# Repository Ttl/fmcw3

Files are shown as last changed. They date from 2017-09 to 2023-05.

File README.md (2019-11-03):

# 6 GHz two RX channel FMCW radar design files.

For more information see: https://hforsten.com/third-version-of-homemade-6-ghz-fmcw-radar.html

## SAR image formation steps:

Compile Tensorflow custom operations in `pc/sar/sar_op`. See `BUILDING` file in
that directory for the instructions.

`pc/sar/process_sweeps.py` is used to slice the correct time from the measurement file.

`./process_sweeps.py <log file> <start time> <end time> [decimation factor]`

It writes `sweeps.p` file with the data in the format the image formation scripts know how to read.
To form the SAR image run `./backprojection_tf.py sweeps.p` or `./omegak_tf.py sweeps.p`.
Some variables related to the image formation can be found on the top of the image formation scripts.

Example data can be downloaded from: https://hforsten.com/fmcw3/parking_lot_sar.log

Use start and end times of 20 and 136 for it. Decimation factor should be 1 or
2 for backprojection and 2 for omega-k.

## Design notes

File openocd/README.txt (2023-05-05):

Programs the radar board FPGA and flash memory.

Openocd version 0.11.0 recommended.

To program the FPGA without flash:
$ openocd -f program_fpga.cfg 

To program flash:
$ openocd -f program_flash.cfg

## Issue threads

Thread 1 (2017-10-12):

Have you consider to sell it?

sken79, 2017-10-12:
Your project is impressive, but difficult to realize by newbie: have you consider to sell it?

Ttl, 2017-10-13:
I have considered it, but I'm not going to sell them. Manufacturing them myself would require too much time for it to be worth it and I don't think that there is enough demand for larger scale production. There are also potential legal issues with selling radio devices that can transmit on frequency bands that require license.

Closed 2017-10-13.

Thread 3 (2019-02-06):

Bill of Materials Challenges

zack-emmert, 2019-02-06:
Once again attempting to track down all of the components involved, a large number of entries lack the information necessary to locate them. The majority of entries lack a Manufacturer Part Number, making it very difficult to track down the components. Examples include the 15dB Coupler, and "C_0402b 10n." I have precisely no clue what the second component actually is, and there is significant ambiguity locating the first one. Clarification regarding the MPNs of many of the components would be very helpful.

Ttl, 2019-02-06:
"15 dB Coupler" is the coupler on PA output made of PCB traces, there is nothing to populate.

"C_0402b" is 0402 capacitor footprint. 10n is the value.

I know it could be clearer, but I don't have the time or motivation to fill the manufacturer part numbers. Both of these should have been clear if you would have looked them up in the schematic.

Closed 2019-02-06.

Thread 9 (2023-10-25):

Design Rule Check (DRC) problems of fmcw3

bigbenbell, 2023-10-25:
Dear Henrik,

You really contributed a beautiful fmcw radar design. We are trying to build our own radar system using the design of fmcw3. When outputting Gerber files, there were a large number of errors during running DRC. For example:
1 Error: Annular width (board setup constraints...n annular width 0.1000 mm; actual 0.0000 mm)
2 Error: Clearance violation (netclass 'Default' clearance 0.1300 mm; actual 0.0000 mm)
3 Error: Hole clearance violation...
4 Error: Courtyards overlap...
5 Error: Drill out of range...

**I'm not sure if this will affect the homemade radar.**

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

Closed 2023-10-25.

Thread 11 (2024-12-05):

fmcw board problem

mjk1376, 2024-12-05:
hello, i have order your board from osh and buy it's component and solder them but i have problem. vivado can not determine fpga. i change eeprom ic and program it with my own hex file and when i attach cable the computer show device attachment in device manager but vivado in auto-connect mode it did not know the board. all the voltages are correct. board after attaching to 12 v consume 0.19 A and after i attach type-b cable it show 0.21 A. can you give me hint about the problem.
thanks

Ttl, 2024-12-05:
Vivado is not supported. You need to use openocd. See `openocd` folder.

Closed 2024-12-05.

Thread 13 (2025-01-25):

how to test board

mjk1376, 2025-01-25:
Hello
I have ordered the board and its components. After addressing a few challenges, I am pleased to report that the board's voltage levels are now correct, and the FPGA has been successfully programmed with your provided configuration. The output current is 250mA, as indicated in the schematic. However, there is no signal present at the TX output. Could you kindly advise on the recommended steps for testing the RF component of the board?

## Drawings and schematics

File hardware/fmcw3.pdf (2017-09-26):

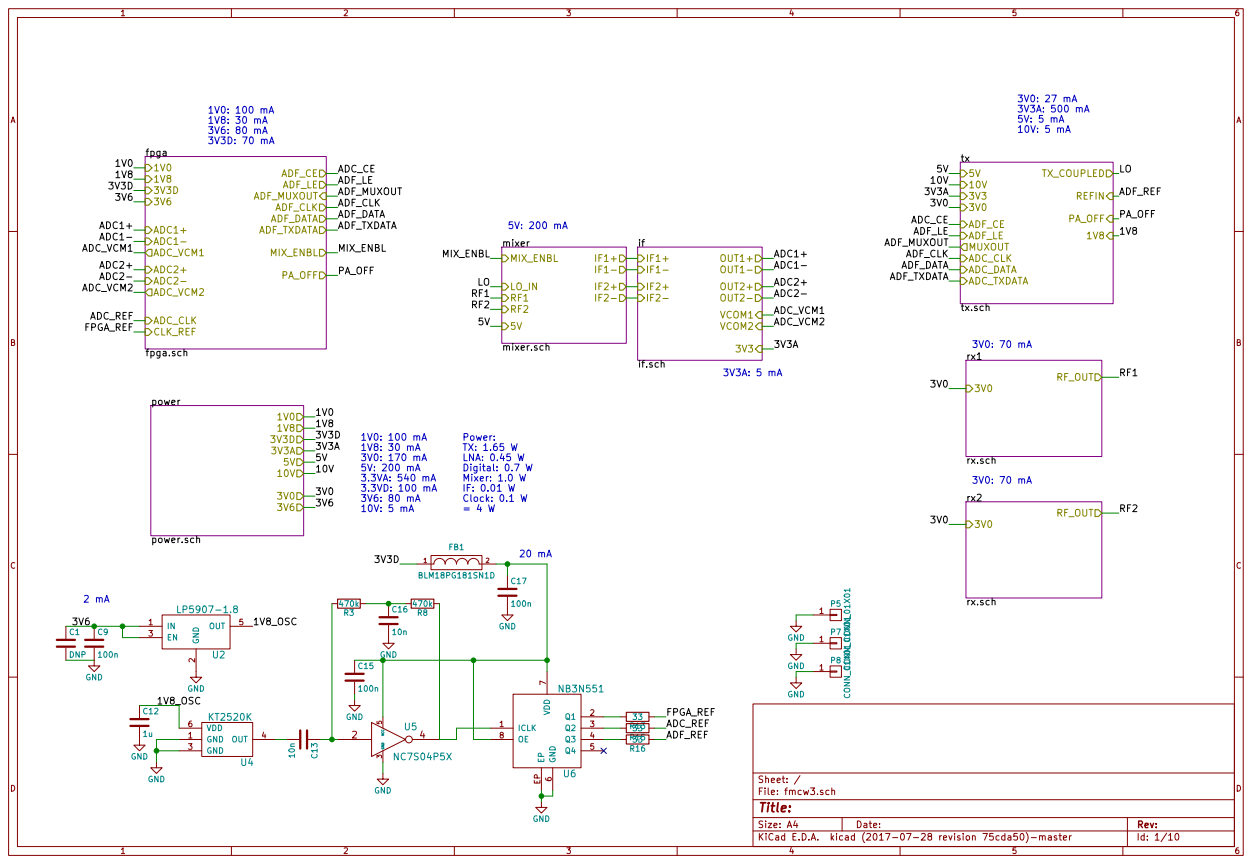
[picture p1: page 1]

Id: 1/10 Title: File: fmcw3.sch Sheet: /

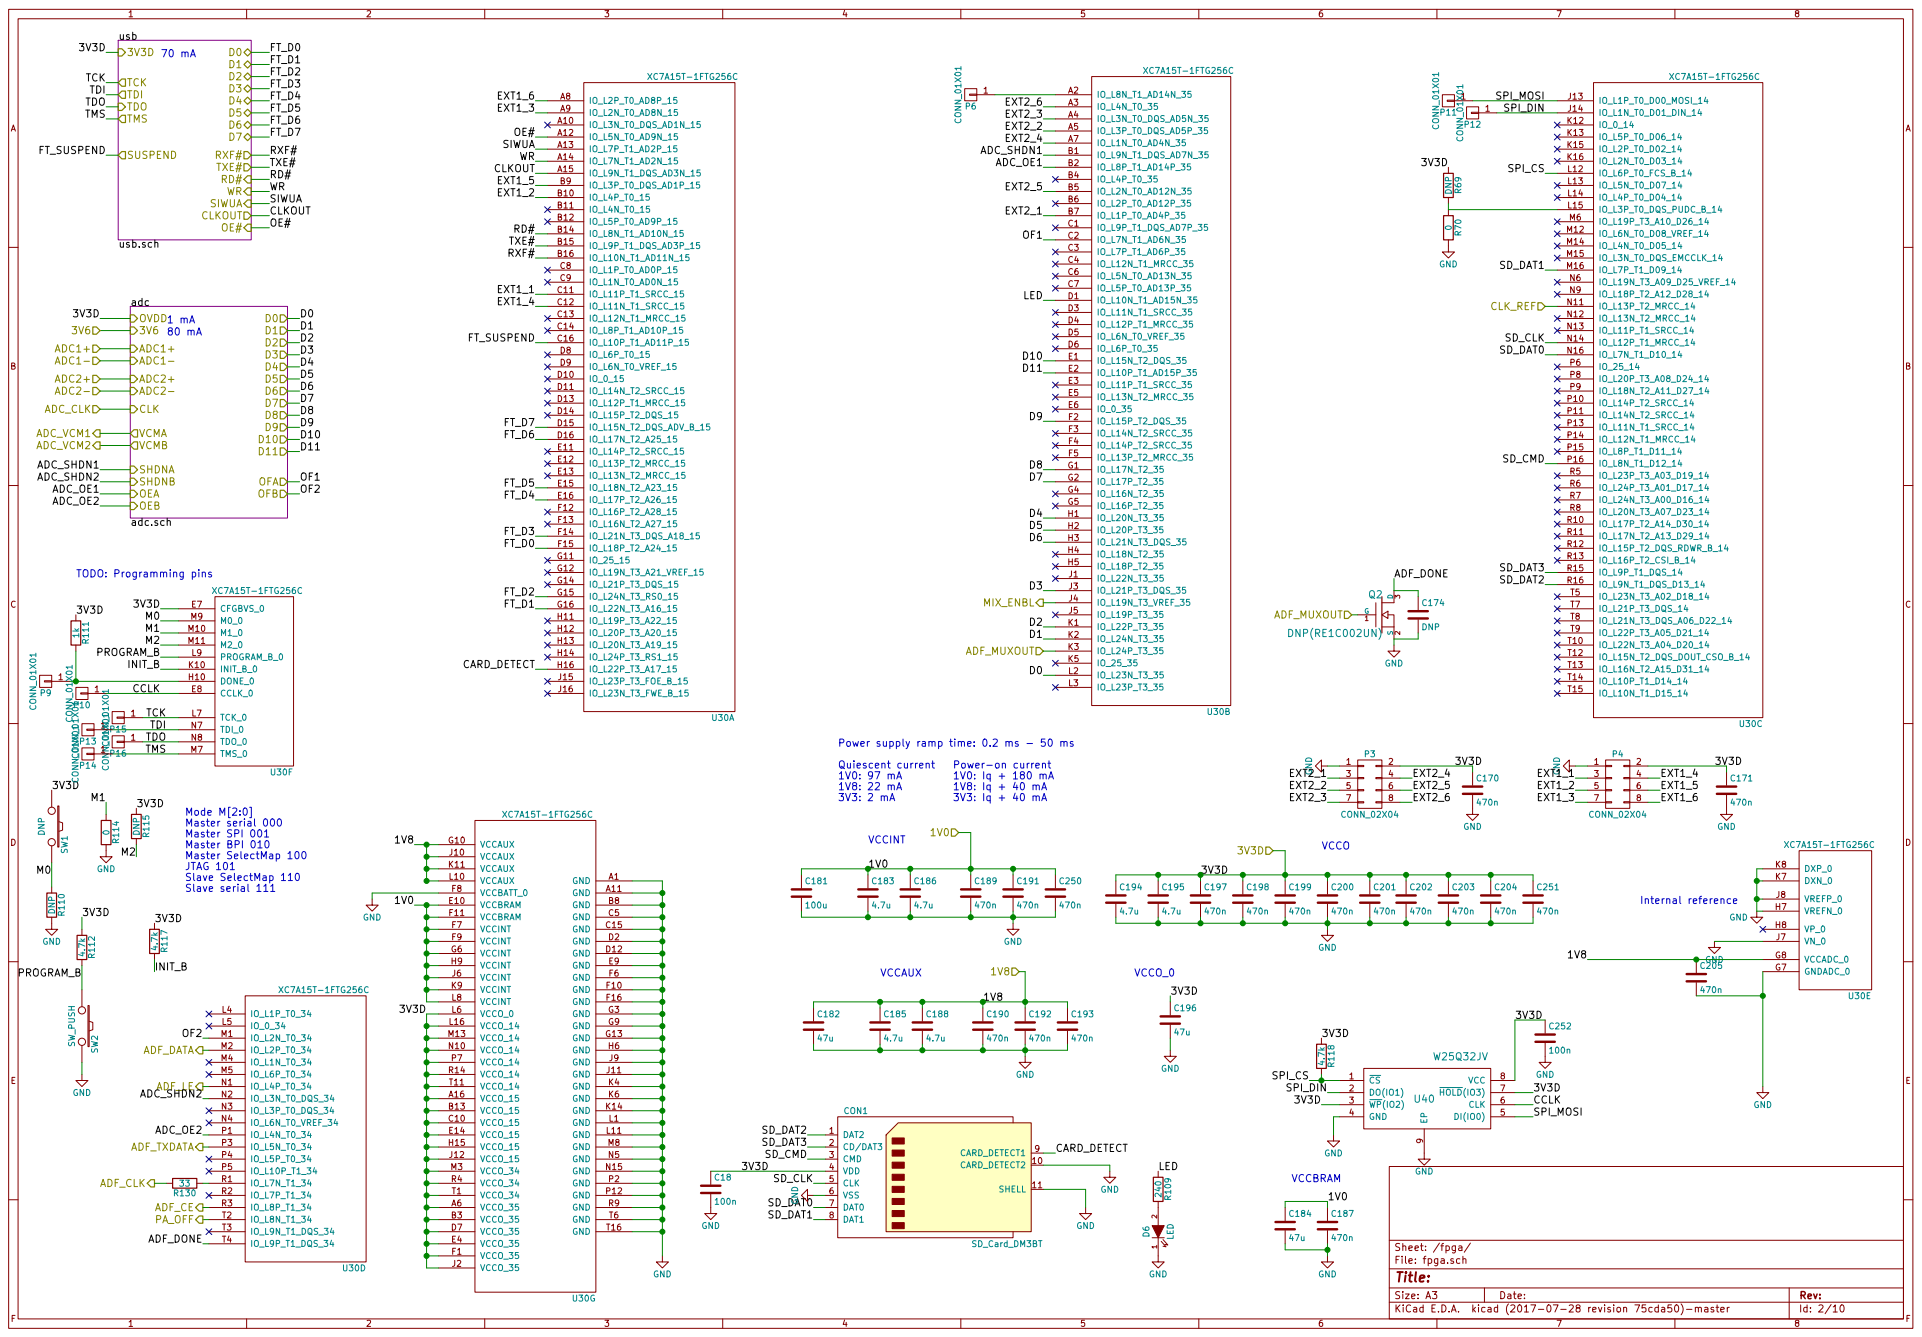
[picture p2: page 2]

SIWUA CLKOUT OE# SUSPEND

Power supply ramp time: 0.2 ms - 50 ms
Internal reference Quiescent current 1V0: 97 mA

Power-on current 1V0: Iq + 180 mA

Id: 2/10 Title: File: fpga.sch Sheet: /fpga/

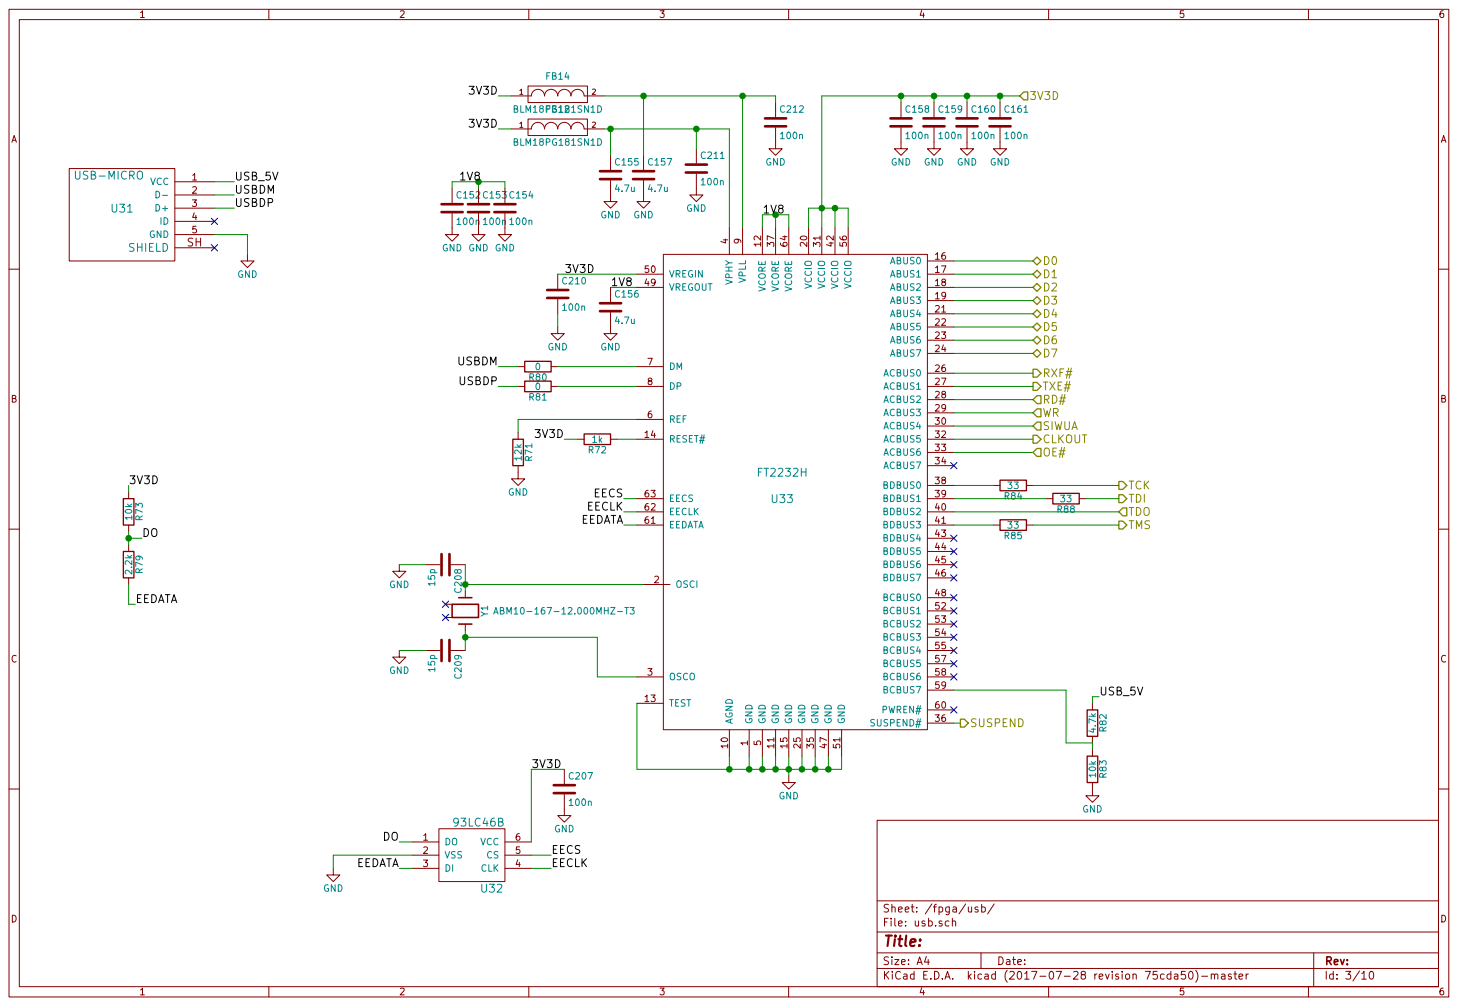
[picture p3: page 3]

Id: 3/10 Title: File: usb.sch Sheet: /fpga/usb/

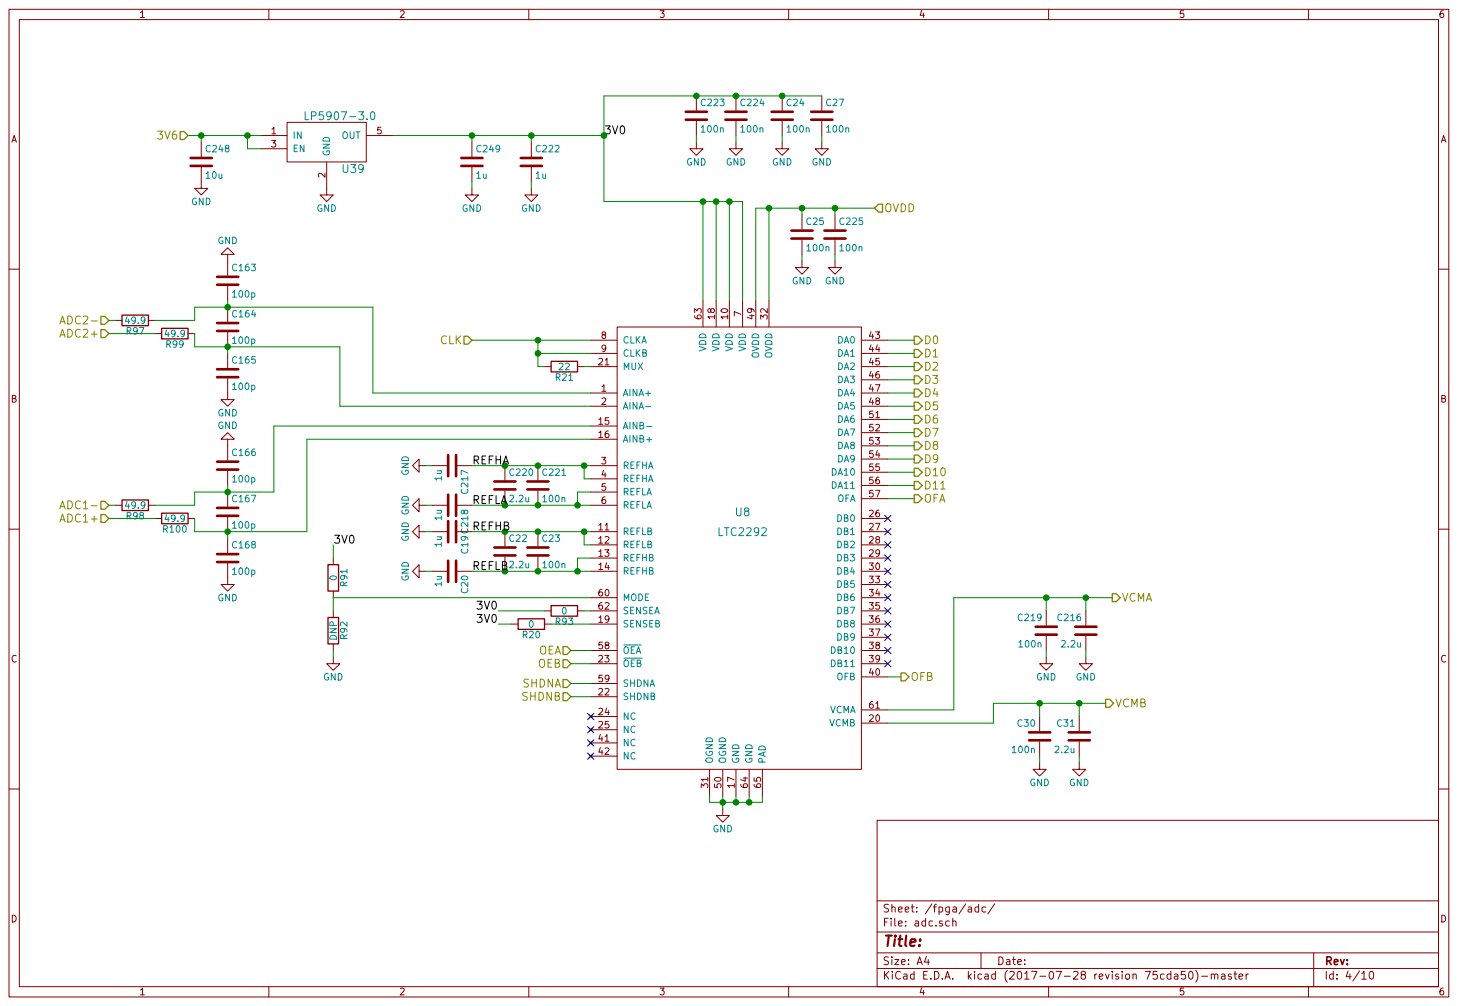
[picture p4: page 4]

7 CLKA 8 CLKB 9 VDD 10 VCMB 20 DB4 30 OFB 40 OGND 50 MODE 60 REFLB 11 MUX 21 OGND 31 NC 41 DA6 51 VCMA 61 REFLB 12 SHDNB 22 OVDD 32 NC 42 DA7 52 SENSEA 62 REFHB 13 OEB 23 DB5 33 DA0 43 DA8 53 VDD 63 REFHB 14 NC 24 DB6 34 DA1 44 DA9 54 GND 64 AINB- 15 NC 25 DB7 35 DA2 45 DA10 55 PAD 65 AINB+ 16 DB0 26 DB8 36 DA3 46 DA11 56 GND 17 DB1 27 DB9 37 DA4 47 OFA 57 VDD 18 DB2 28 DB10 38 DA5 48 OEA 58 SENSEB 19 DB3 29 DB11 39 OVDD 49 SHDNA 59 U8

Id: 4/10 Title: File: adc.sch Sheet: /fpga/adc/

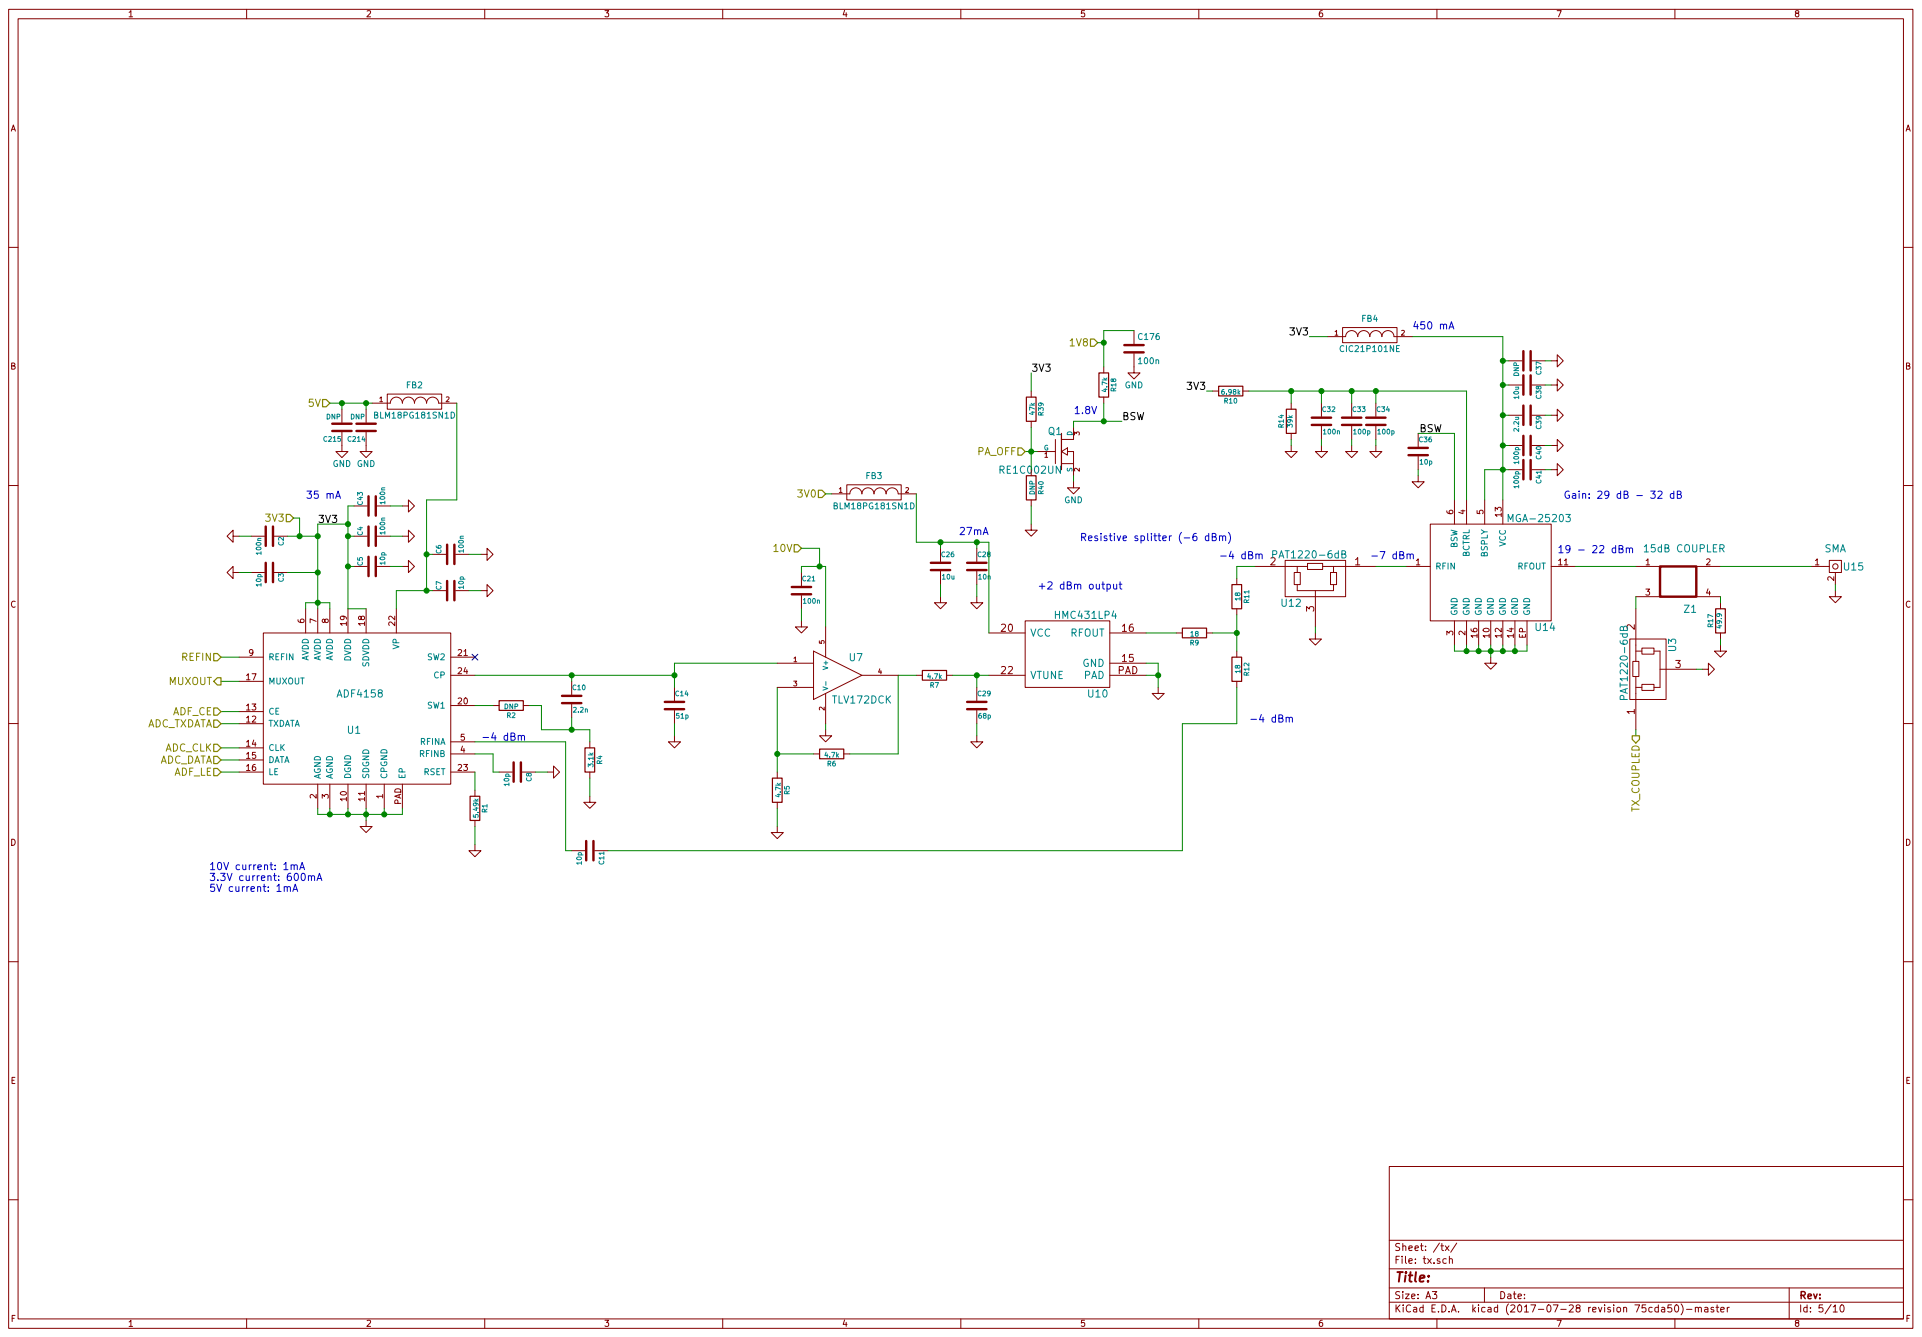
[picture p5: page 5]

6 GND 10 RFOUT 11 GND 12 VCC 13 GND 14 GND 16 GND EPU14 MGA-25203 C40 100p C39 2.2u 10u C38 DNP C37 C33

8 REFIN 9 DGND 10 SW1 20 SDGND 11 SW2 21 TXDATA 12 VP 22 CE 13 RSET 23 CLK 14 CP 24 DATA 15

Id: 5/10 Title: File: tx.sch Sheet: /tx/

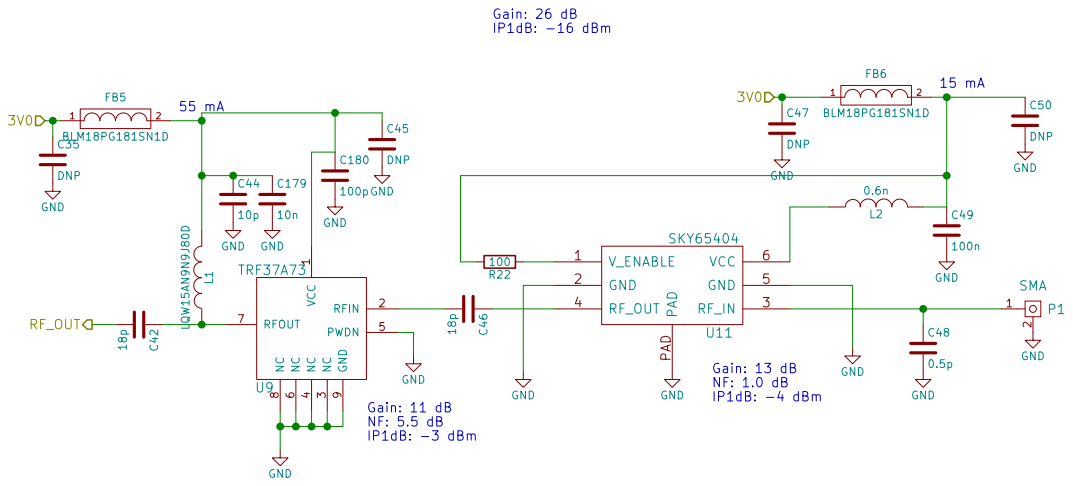
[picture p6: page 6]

IP1dB: -16 dBm
C47 DNP GND Gain: 13 dB NF: 1.0 dB

Gain: 11 dB NF: 5.5 dB

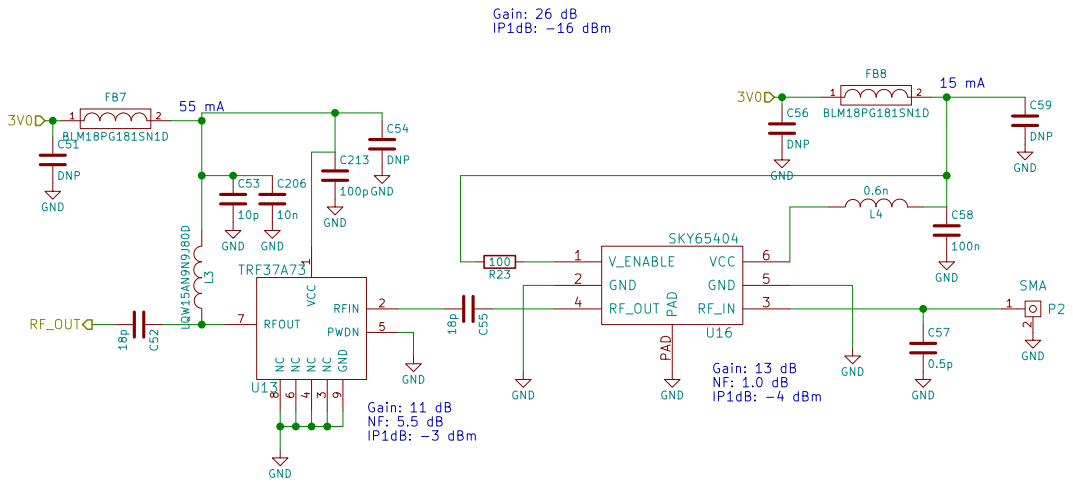
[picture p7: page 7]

IP1dB: -16 dBm
C56 DNP GND Gain: 13 dB NF: 1.0 dB

Gain: 11 dB NF: 5.5 dB

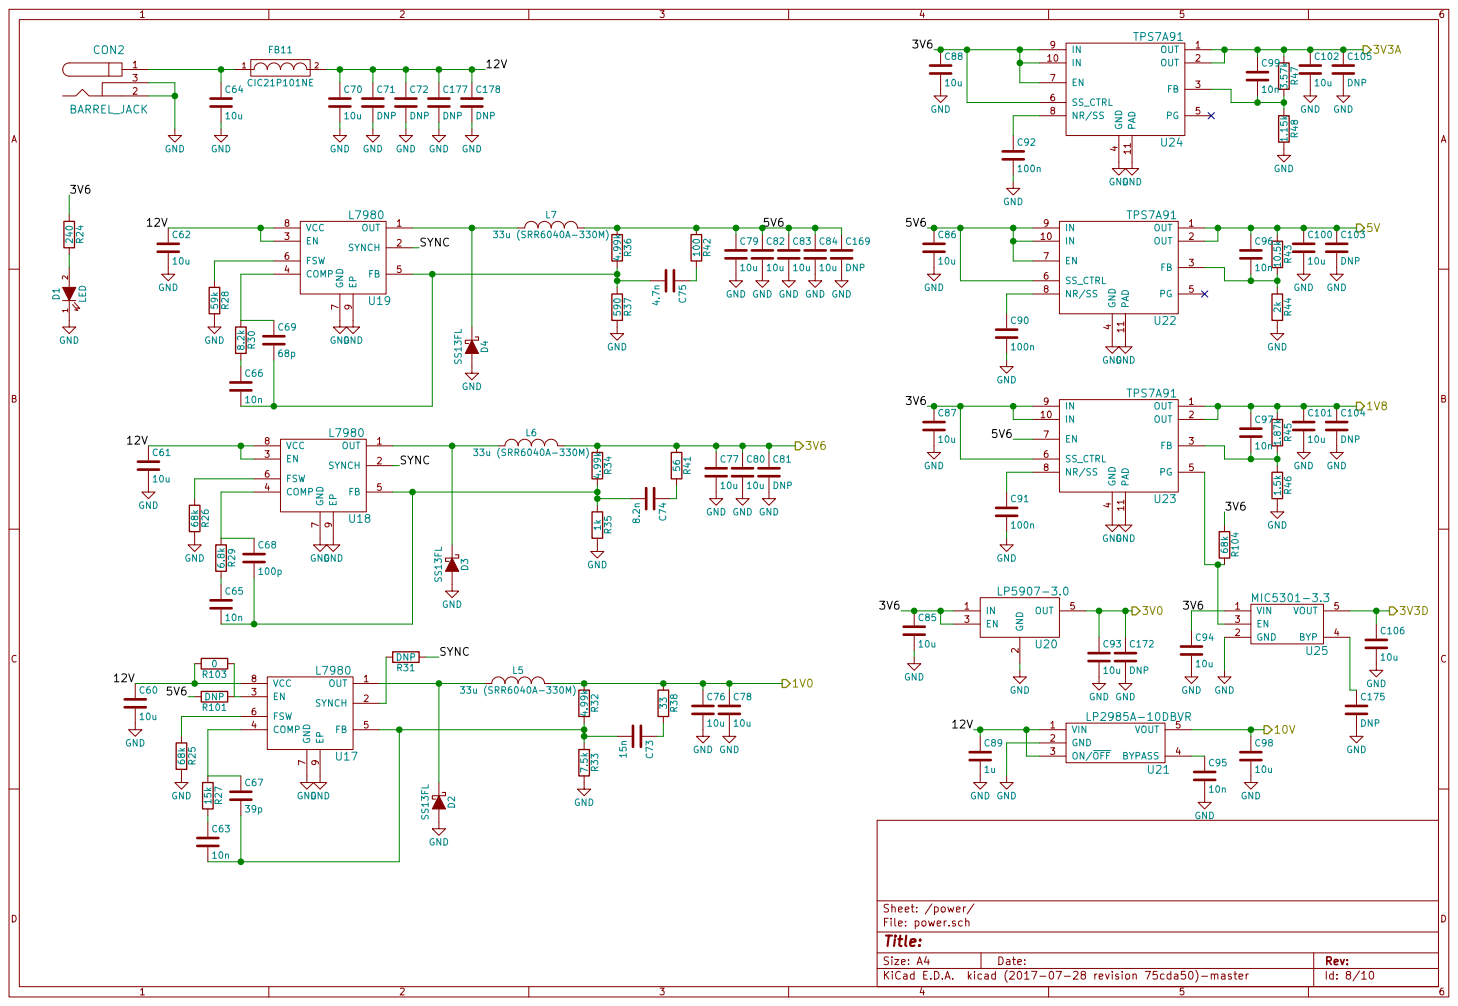
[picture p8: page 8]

4 PG 5 SS_CTRL 6 EN 7 NR/SS 8

1 2 D1 LED GND240 R24 3V6 OUT 1 SYNCH EN 2

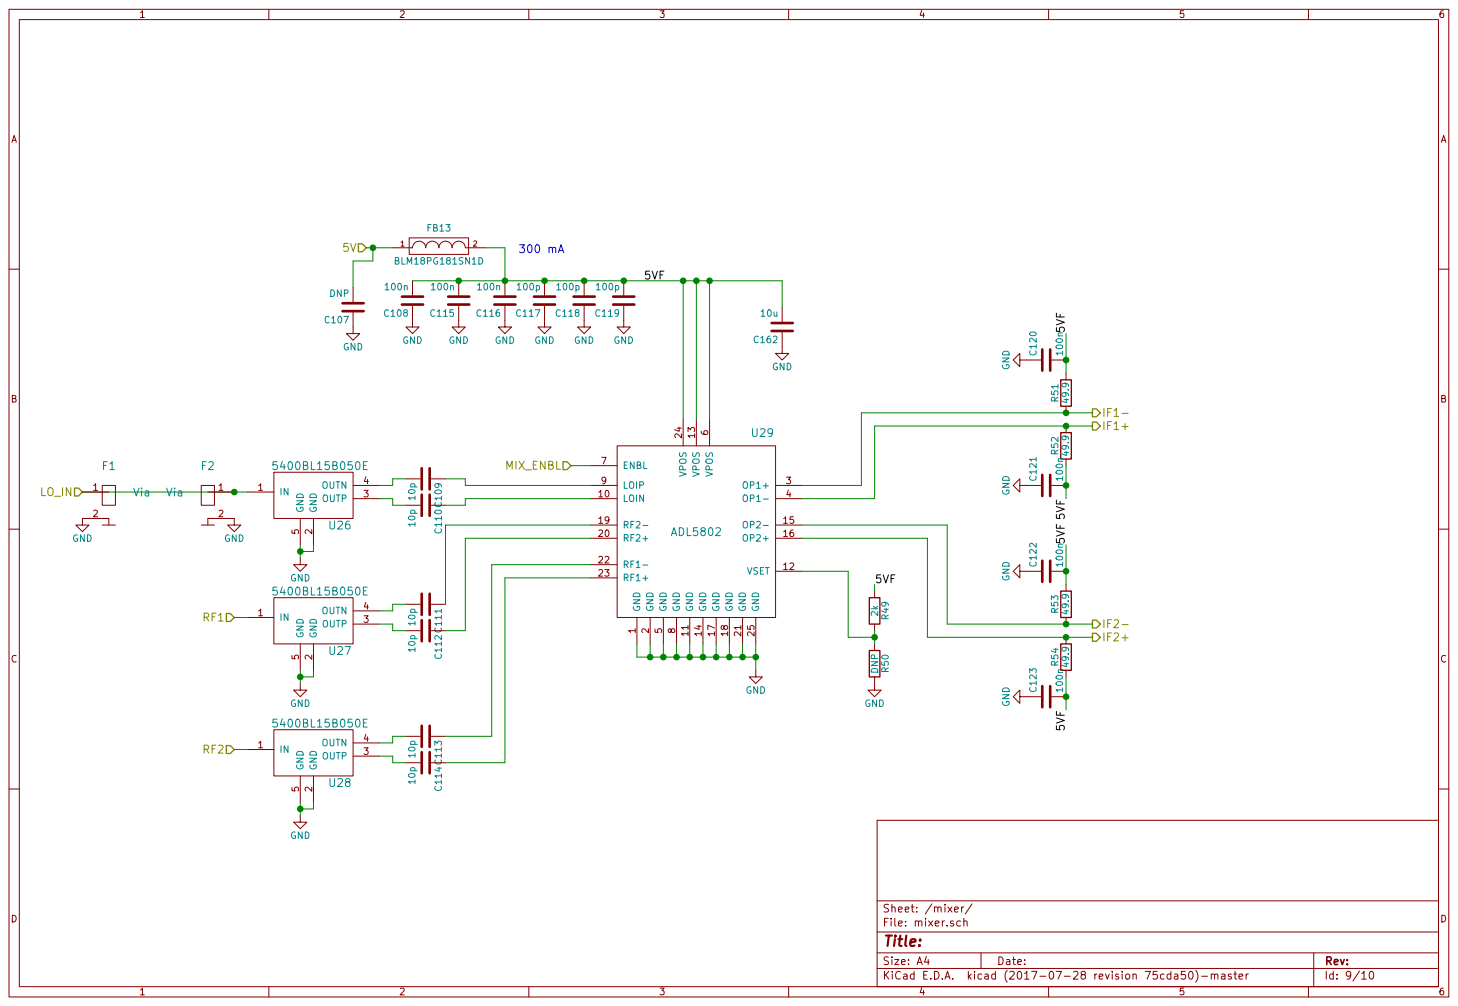
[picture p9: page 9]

Id: 9/10 Title: File: mixer.sch Sheet: /mixer/ GND

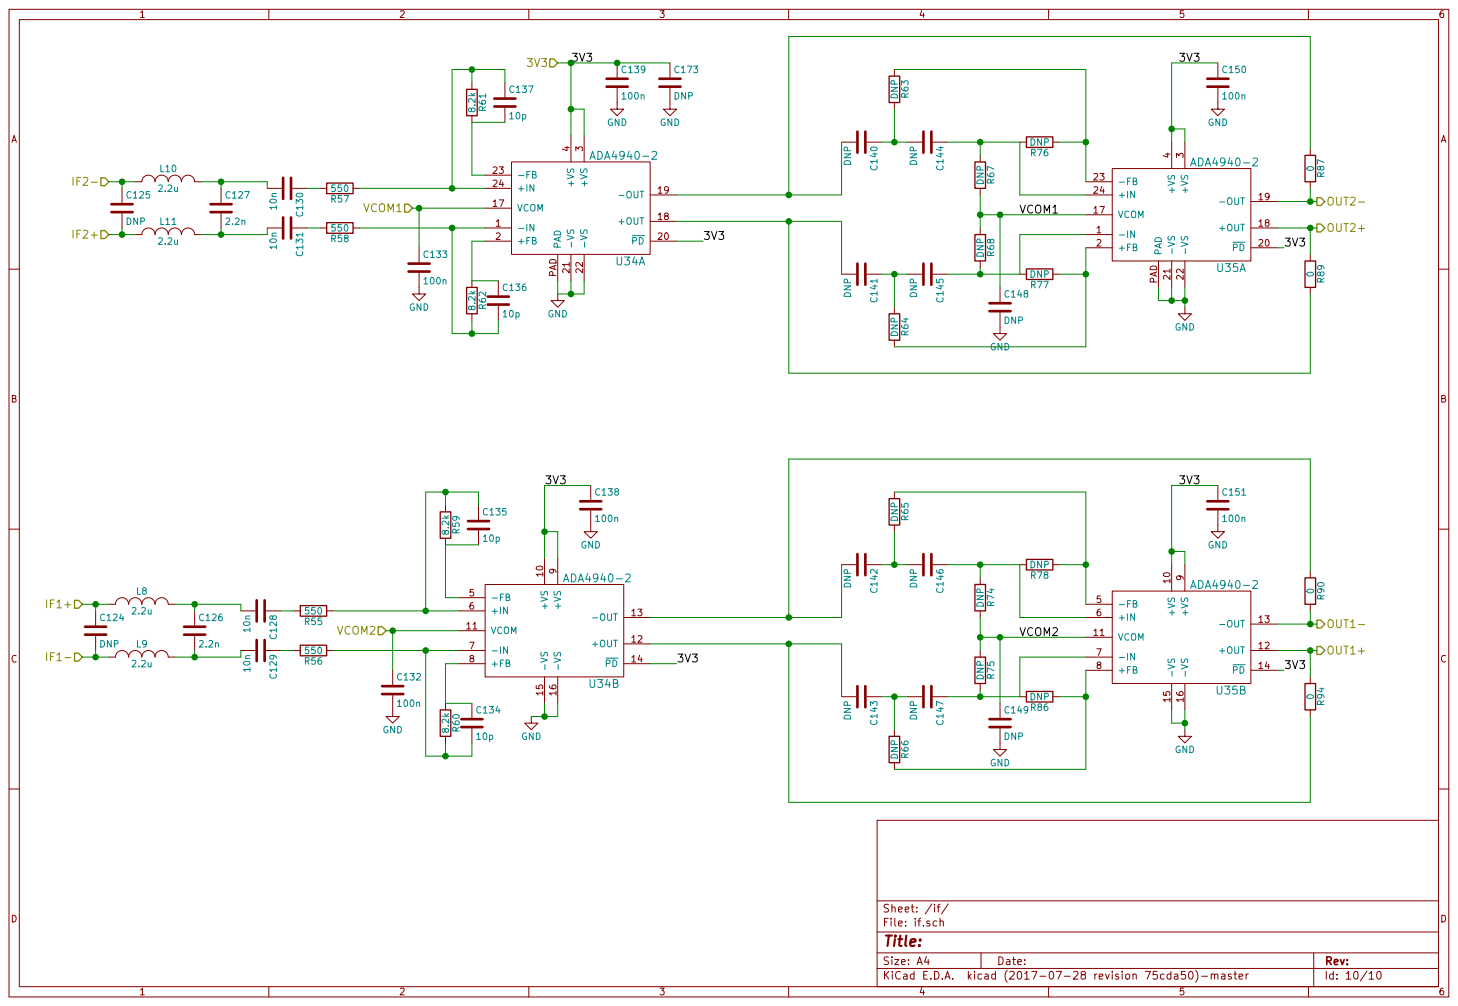
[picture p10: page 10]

Id: 10/10 Title: File: if.sch Sheet: /if/

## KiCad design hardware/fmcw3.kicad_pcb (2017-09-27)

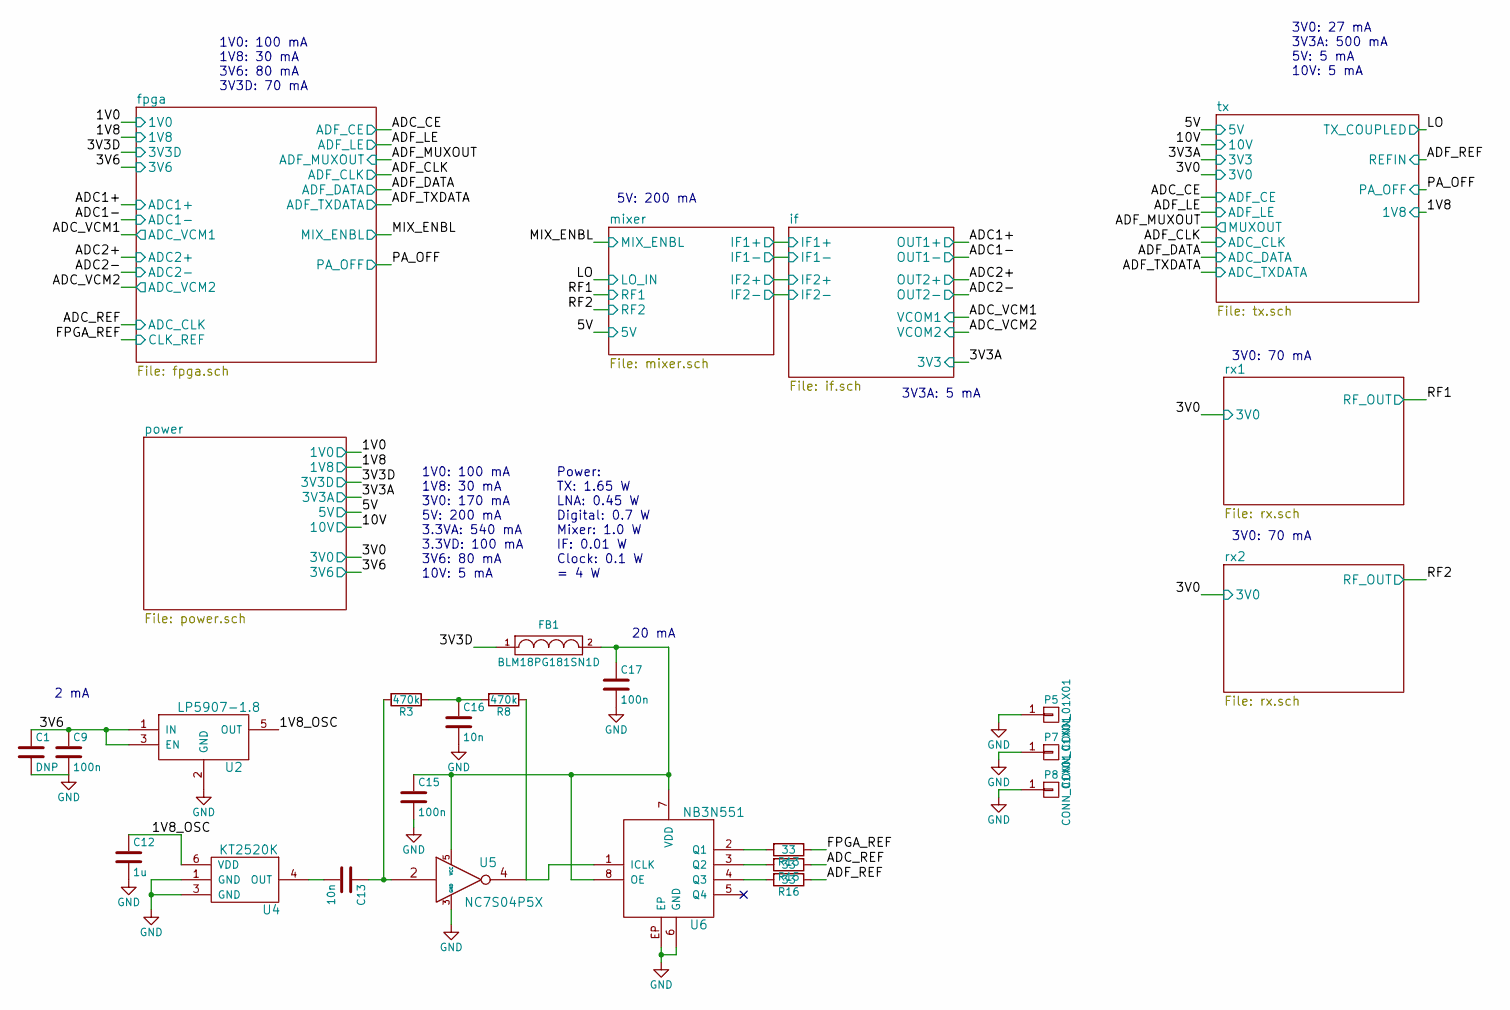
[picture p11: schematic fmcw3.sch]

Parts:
C1: DNP; C_0805b
C9, C15, C17: 100n; C_0402b
C12: 1u; C_0603b
C13, C16: 10n; C_0402b
FB1: BLM18PG181SN1D; C_0603b
P5, P7, P8: CONN_01X01; MountingHole_3.2mm_M3_Pad_Via_mod
R3, R8: 470k; R_0402b
R13, R15, R16: 33; R_0402b
U2: LP5907-1.8; SOT-23-5
U4: KT2520K
U5: NC7S04P5X; SOT-353_SC-70-5
U6: NB3N551; DFN-8

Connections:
/1V8_OSC: C12.1, U2.5 (OUT), U4.6 (VDD)
/3V3D: FB1.1; also elsewhere on the board
/3V6: C1.1, C9.1, U2.1 (IN), U2.3 (EN); also elsewhere on the board
/ADC_REF: R15.1; also elsewhere on the board
/ADF_REF: R16.1; also elsewhere on the board
/FPGA_REF: R13.1; also elsewhere on the board
GND: C1.2, C9.2, C12.2, C15.2, C16.2, C17.2, P5.1, P7.1, P8.1, U2.2 (GND), U4.1 (GND), U4.3 (GND), U5.3 (GND), U6.6 (GND), U6.EP; also elsewhere on the board
unnamed: C13.1, R3.2, U5.2
unnamed: C13.2, U4.4 (OUT)
unnamed: C15.1, C17.1, FB1.2, U5.5 (VCC), U6.7 (VDD), U6.8 (OE)
unnamed: C16.1, R3.1, R8.2
unnamed: R8.1, U5.4, U6.1 (ICLK)
unnamed: R13.2, U6.2 (Q1)
unnamed: R15.2, U6.3 (Q2)
unnamed: R16.2, U6.4 (Q3)

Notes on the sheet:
5V: 200 mA
3V0: 70 mA
2 mA
1V0: 100 mA 1V8: 30 mA 3V0: 170 mA 5V: 200 mA 3.3VA: 540 mA 3.3VD: 100 mA 3V6: 80 mA 10V: 5 mA
3V0: 27 mA 3V3A: 500 mA 5V: 5 mA 10V: 5 mA
3V3A: 5 mA
1V0: 100 mA 1V8: 30 mA 3V6: 80 mA 3V3D: 70 mA
20 mA
Power: TX: 1.65 W LNA: 0.45 W Digital: 0.7 W Mixer: 1.0 W IF: 0.01 W Clock: 0.1 W = 4 W

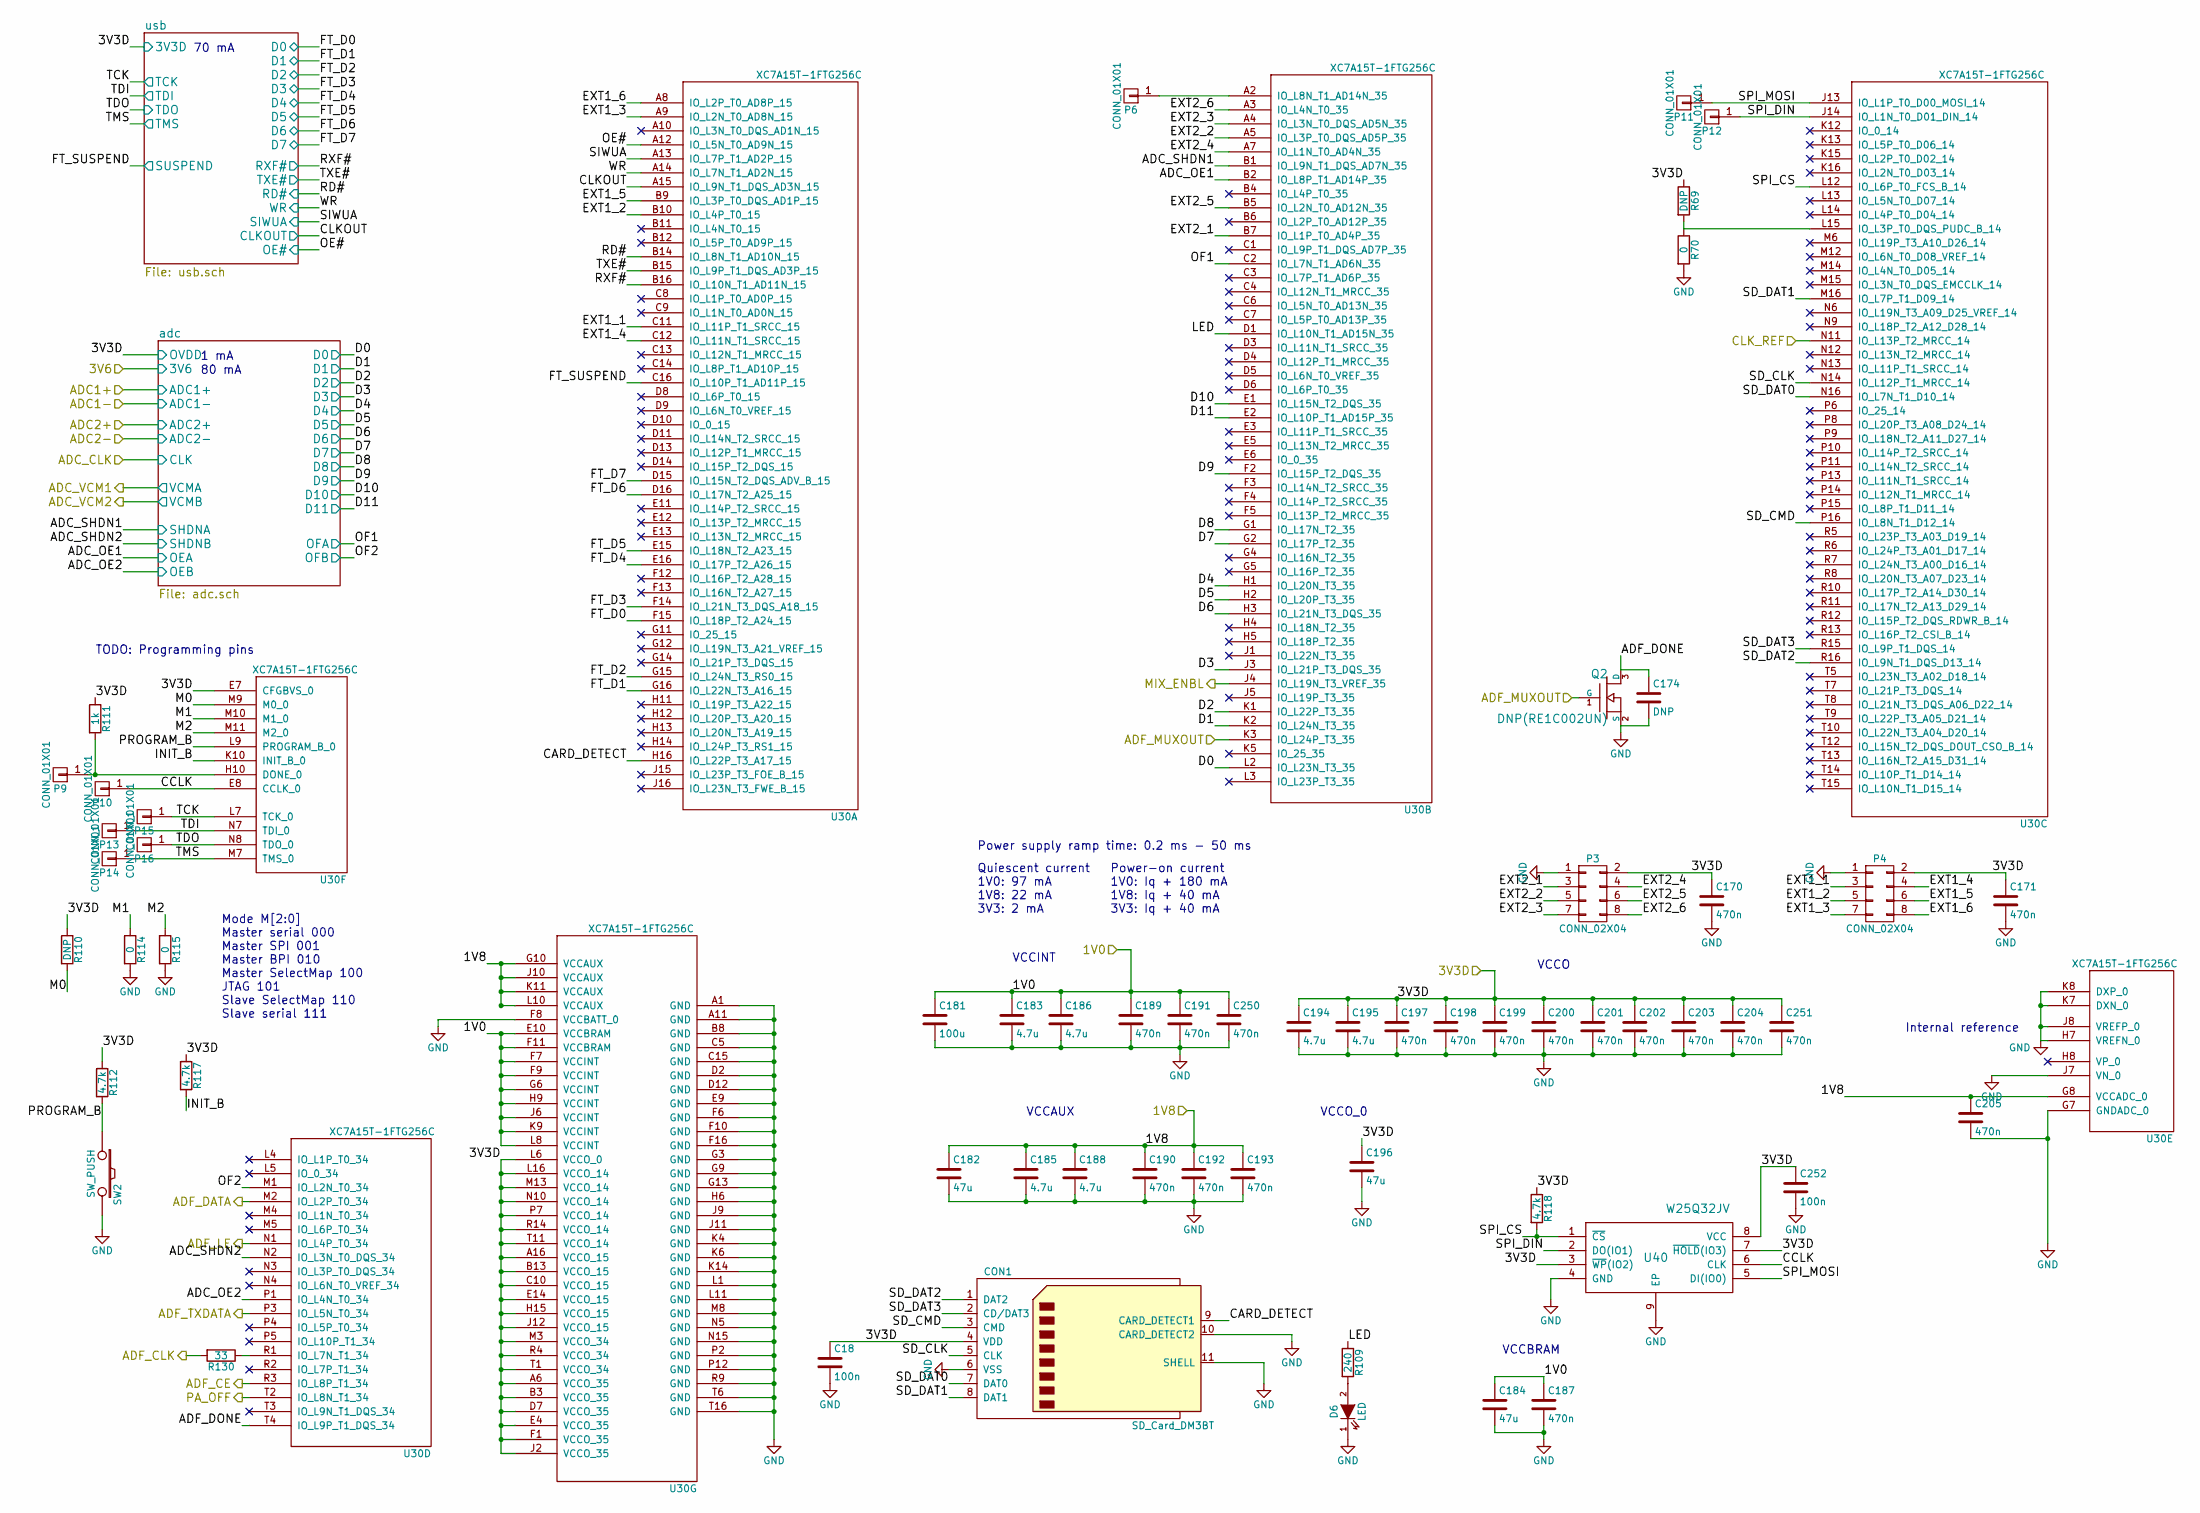
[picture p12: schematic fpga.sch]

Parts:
C18, C252: 100n; C_0402b
C170, C171, C187, C189, C190, C191, C192, C193, C197, C198, C199, C200, C201, C202, C203, C204, C205, C250, C251: 470n; C_0402b
C174: DNP; C_0402b
C181: 100u; C_1210
C182, C184, C196: 47u; C_1206
C183, C185, C186, C188, C194, C195: 4.7u; C_0805b
CON1: SD_Card_DM3BT; DM3BT-DSF-PEJS
D6: LED; LED_0603
P3, P4: CONN_02X04; Pin_Header_Straight_2x04_Pitch2.54mm_SMD
P6, P9, P10, P11, P12, P13, P14, P15, P16: CONN_01X01; TP_1.00
Q2: DNP(RE1C002UN); SOT-416
R69, R110: DNP; R_0402b
R70, R114, R115: 0; R_0402b
R109: 240; R_0402b
R111: 1k; R_0402b
R112, R117, R118: 4.7k; R_0402b
R130: 33; R_0402b
SW2: SW_PUSH; EVP-AWBA2A
U30: XC7A15T-1FTG256C; FTG256
U40: W25Q32JV; DFN-S-8-1EP_6x5mm_Pitch1.27mm

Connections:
/1V0: C181.1, C183.1, C184.1, C186.1, C187.1, C189.1, C191.1, C250.1, U30.E10 (VCCBRAM), U30.F7 (VCCINT), U30.F9 (VCCINT), U30.F11 (VCCBRAM), U30.G6 (VCCINT), U30.H9 (VCCINT), U30.J6 (VCCINT), U30.K9 (VCCINT), U30.L8 (VCCINT); also elsewhere on the board
/1V8: C182.1, C185.1, C188.1, C190.1, C192.1, C193.1, C205.1, U30.G8 (VCCADC_0), U30.G10 (VCCAUX), U30.J10 (VCCAUX), U30.K11 (VCCAUX), U30.L10 (VCCAUX); also elsewhere on the board
/3V3D: C18.1, C170.1, C171.1, C194.1, C195.1, C196.1, C197.1, C198.1, C199.1, C200.1, C201.1, C202.1, C203.1, C204.1, C251.1, C252.1, CON1.4 (VDD), P3.2, P4.2, R69.1, R110.1, R111.1, R112.1, R117.1, R118.1, U30.A6 (VCCO_35), U30.A16 (VCCO_15), U30.B3 (VCCO_35), U30.B13 (VCCO_15), U30.C10 (VCCO_15), U30.D7 (VCCO_35), U30.E4 (VCCO_35), U30.E7 (CFGBVS_0), U30.E14 (VCCO_15), U30.F1 (VCCO_35), U30.H15 (VCCO_15), U30.J2 (VCCO_35), U30.J12 (VCCO_15), U30.L6 (VCCO_0), U30.L16 (VCCO_14), U30.M3 (VCCO_34), U30.M13 (VCCO_14), U30.N10 (VCCO_14), U30.P7 (VCCO_14), U30.R4 (VCCO_34), U30.R14 (VCCO_14), U30.T1 (VCCO_34), U30.T11 (VCCO_14), U40.3 (~WP~(IO2)), U40.7 (~HOLD~(IO3)), U40.8 (VCC); also elsewhere on the board
/ADC_CE: U30.R3 (IO_L8P_T1_34); also elsewhere on the board
/ADF_CLK: R130.2; also elsewhere on the board
/ADF_DATA: U30.M2 (IO_L2P_T0_34); also elsewhere on the board
/ADF_LE: U30.N1 (IO_L4P_T0_34); also elsewhere on the board
/ADF_MUXOUT: Q2.1 (G), U30.K3 (IO_L24P_T3_35); also elsewhere on the board
/ADF_TXDATA: U30.P3 (IO_L5N_T0_34); also elsewhere on the board
/FPGA_REF: U30.N11 (IO_L13P_T2_MRCC_14); also elsewhere on the board
/MIX_ENBL: U30.J4 (IO_L19N_T3_VREF_35); also elsewhere on the board
/PA_OFF: U30.T2 (IO_L8N_T1_34); also elsewhere on the board
/fpga/ADC_OE1: U30.B2 (IO_L8P_T1_AD14P_35); also elsewhere on the board
/fpga/ADC_OE2: U30.P1 (IO_L4N_T0_34); also elsewhere on the board
/fpga/ADC_SHDN1: U30.B1 (IO_L9N_T1_DQS_AD7N_35); also elsewhere on the board
/fpga/ADC_SHDN2: U30.N2 (IO_L3N_T0_DQS_34); also elsewhere on the board
/fpga/ADF_DONE: C174.1, Q2.3 (D), U30.T4 (IO_L9P_T1_DQS_34)
/fpga/CARD_DETECT: CON1.9 (CARD_DETECT1), U30.H16 (IO_L22P_T3_A17_15)
/fpga/CCLK: P10.1, U30.E8 (CCLK_0), U40.6 (CLK)
/fpga/CLKOUT: U30.A15 (IO_L9N_T1_DQS_AD3N_15); also elsewhere on the board
/fpga/D0: U30.L2 (IO_L23N_T3_35); also elsewhere on the board
/fpga/D1: U30.K2 (IO_L24N_T3_35); also elsewhere on the board
/fpga/D2: U30.K1 (IO_L22P_T3_35); also elsewhere on the board
/fpga/D3: U30.J3 (IO_L21P_T3_DQS_35); also elsewhere on the board
/fpga/D4: U30.H1 (IO_L20N_T3_35); also elsewhere on the board
/fpga/D5: U30.H2 (IO_L20P_T3_35); also elsewhere on the board
/fpga/D6: U30.H3 (IO_L21N_T3_DQS_35); also elsewhere on the board
/fpga/D7: U30.G2 (IO_L17P_T2_35); also elsewhere on the board
/fpga/D8: U30.G1 (IO_L17N_T2_35); also elsewhere on the board
/fpga/D9: U30.F2 (IO_L15P_T2_DQS_35); also elsewhere on the board
/fpga/D10: U30.E1 (IO_L15N_T2_DQS_35); also elsewhere on the board
/fpga/D11: U30.E2 (IO_L10P_T1_AD15P_35); also elsewhere on the board
/fpga/EXT1_1: P4.3, U30.C11 (IO_L11P_T1_SRCC_15)
/fpga/EXT1_2: P4.5, U30.B10 (IO_L4P_T0_15)
/fpga/EXT1_3: P4.7, U30.A9 (IO_L2N_T0_AD8N_15)
/fpga/EXT1_4: P4.4, U30.C12 (IO_L11N_T1_SRCC_15)
/fpga/EXT1_5: P4.6, U30.B9 (IO_L3P_T0_DQS_AD1P_15)
/fpga/EXT1_6: P4.8, U30.A8 (IO_L2P_T0_AD8P_15)
/fpga/EXT2_1: P3.3, U30.B7 (IO_L1P_T0_AD4P_35)
/fpga/EXT2_2: P3.5, U30.A5 (IO_L3P_T0_DQS_AD5P_35)
/fpga/EXT2_3: P3.7, U30.A4 (IO_L3N_T0_DQS_AD5N_35)
/fpga/EXT2_4: P3.4, U30.A7 (IO_L1N_T0_AD4N_35)
/fpga/EXT2_5: P3.6, U30.B5 (IO_L2N_T0_AD12N_35)
/fpga/EXT2_6: P3.8, U30.A3 (IO_L4N_T0_35)
/fpga/FT_D0: U30.F15 (IO_L18P_T2_A24_15); also elsewhere on the board
/fpga/FT_D1: U30.G16 (IO_L22N_T3_A16_15); also elsewhere on the board
/fpga/FT_D2: U30.G15 (IO_L24N_T3_RS0_15); also elsewhere on the board
/fpga/FT_D3: U30.F14 (IO_L21N_T3_DQS_A18_15); also elsewhere on the board
/fpga/FT_D4: U30.E16 (IO_L17P_T2_A26_15); also elsewhere on the board
/fpga/FT_D5: U30.E15 (IO_L18N_T2_A23_15); also elsewhere on the board
/fpga/FT_D6: U30.D16 (IO_L17N_T2_A25_15); also elsewhere on the board
/fpga/FT_D7: U30.D15 (IO_L15N_T2_DQS_ADV_B_15); also elsewhere on the board
/fpga/FT_SUSPEND: U30.C16 (IO_L10P_T1_AD11P_15); also elsewhere on the board
/fpga/INIT_B: R117.2, U30.K10 (INIT_B_0)
/fpga/LED: R109.1, U30.D1 (IO_L10N_T1_AD15N_35)
/fpga/M0: R110.2, U30.M9 (M0_0)
/fpga/M1: R114.1, U30.M10 (M1_0)
/fpga/M2: R115.1, U30.M11 (M2_0)
/fpga/OE#: U30.A12 (IO_L5N_T0_AD9N_15); also elsewhere on the board
/fpga/OF1: U30.C2 (IO_L7N_T1_AD6N_35); also elsewhere on the board
/fpga/OF2: U30.M1 (IO_L2N_T0_34); also elsewhere on the board
/fpga/PROGRAM_B: R112.2, SW2.1, U30.L9 (PROGRAM_B_0)
/fpga/RD#: U30.B14 (IO_L8N_T1_AD10N_15); also elsewhere on the board
/fpga/RXF#: U30.B16 (IO_L10N_T1_AD11N_15); also elsewhere on the board
/fpga/SD_CLK: CON1.5 (CLK), U30.N14 (IO_L12P_T1_MRCC_14)
/fpga/SD_CMD: CON1.3 (CMD), U30.P16 (IO_L8N_T1_D12_14)
/fpga/SD_DAT0: CON1.7 (DAT0), U30.N16 (IO_L7N_T1_D10_14)
/fpga/SD_DAT1: CON1.8 (DAT1), U30.M16 (IO_L7P_T1_D09_14)
/fpga/SD_DAT2: CON1.1 (DAT2), U30.R16 (IO_L9N_T1_DQS_D13_14)
/fpga/SD_DAT3: CON1.2 (CD/DAT3), U30.R15 (IO_L9P_T1_DQS_14)
/fpga/SIWUA: U30.A13 (IO_L7P_T1_AD2P_15); also elsewhere on the board
/fpga/SPI_CS: R118.2, U30.L12 (IO_L6P_T0_FCS_B_14), U40.1 (~CS)
/fpga/SPI_DIN: P12.1, U30.J14 (IO_L1N_T0_D01_DIN_14), U40.2 (DO(IO1))
/fpga/SPI_MOSI: P11.1, U30.J13 (IO_L1P_T0_D00_MOSI_14), U40.5 (DI(IO0))
/fpga/TCK: P15.1, U30.L7 (TCK_0); also elsewhere on the board
/fpga/TDI: P13.1, U30.N7 (TDI_0); also elsewhere on the board
/fpga/TDO: P16.1, U30.N8 (TDO_0); also elsewhere on the board
/fpga/TMS: P14.1, U30.M7 (TMS_0); also elsewhere on the board
/fpga/TXE#: U30.B15 (IO_L9P_T1_DQS_AD3P_15); also elsewhere on the board
/fpga/WR: U30.A14 (IO_L7N_T1_AD2N_15); also elsewhere on the board
GND: C18.2, C170.2, C171.2, C174.2, C181.2, C182.2, C183.2, C184.2, C185.2, C186.2, C187.2, C188.2, C189.2, C190.2, C191.2, C192.2, C193.2, C194.2, C195.2, C196.2, C197.2, C198.2, C199.2, C200.2, C201.2, C202.2, C203.2, C204.2, C205.2, C250.2, C251.2, C252.2, CON1.6 (VSS), CON1.10 (CARD_DETECT2), CON1.11 (SHELL), D6.1 (K), P3.1, P4.1, Q2.2 (S), R70.2, R114.2, R115.2, SW2.2, U30.A1 (GND), U30.A11 (GND), U30.B8 (GND), U30.C5 (GND), U30.C15 (GND), U30.D2 (GND), U30.D12 (GND), U30.E9 (GND), U30.F6 (GND), U30.F8 (VCCBATT_0), U30.F10 (GND), U30.F16 (GND), U30.G3 (GND), U30.G7 (GNDADC_0), U30.G9 (GND), U30.G13 (GND), U30.H6 (GND), U30.H7 (VREFN_0), U30.J7 (VN_0), U30.J8 (VREFP_0), U30.J9 (GND), U30.J11 (GND), U30.K4 (GND), U30.K6 (GND), U30.K7 (DXN_0), U30.K8 (DXP_0), U30.K14 (GND), U30.L1 (GND), U30.L11 (GND), U30.M8 (GND), U30.N5 (GND), U30.N15 (GND), U30.P2 (GND), U30.P12 (GND), U30.R9 (GND), U30.T6 (GND), U30.T16 (GND), U40.4 (GND), U40.9 (EP); also elsewhere on the board
unnamed: D6.2 (A), R109.2
unnamed: P6.1, U30.A2 (IO_L8N_T1_AD14N_35)
unnamed: P9.1, R111.2, U30.H10 (DONE_0)
unnamed: R69.2, R70.1, U30.L15 (IO_L3P_T0_DQS_PUDC_B_14)
unnamed: R130.1, U30.R1 (IO_L7N_T1_34)

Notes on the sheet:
VCCINT
VCCBRAM
VCCAUX
VCCO_0
VCCO
Internal reference
Quiescent current 1V0: 97 mA 1V8: 22 mA 3V3: 2 mA
Power-on current 1V0: Iq + 180 mA 1V8: Iq + 40 mA 3V3: Iq + 40 mA
Power supply ramp time: 0.2 ms - 50 ms
80 mA
TODO: Programming pins
Mode M[2:0] Master serial 000 Master SPI 001 Master BPI 010 Master SelectMap 100 JTAG 101 Slave SelectMap 110 Slave serial 111
70 mA
1 mA

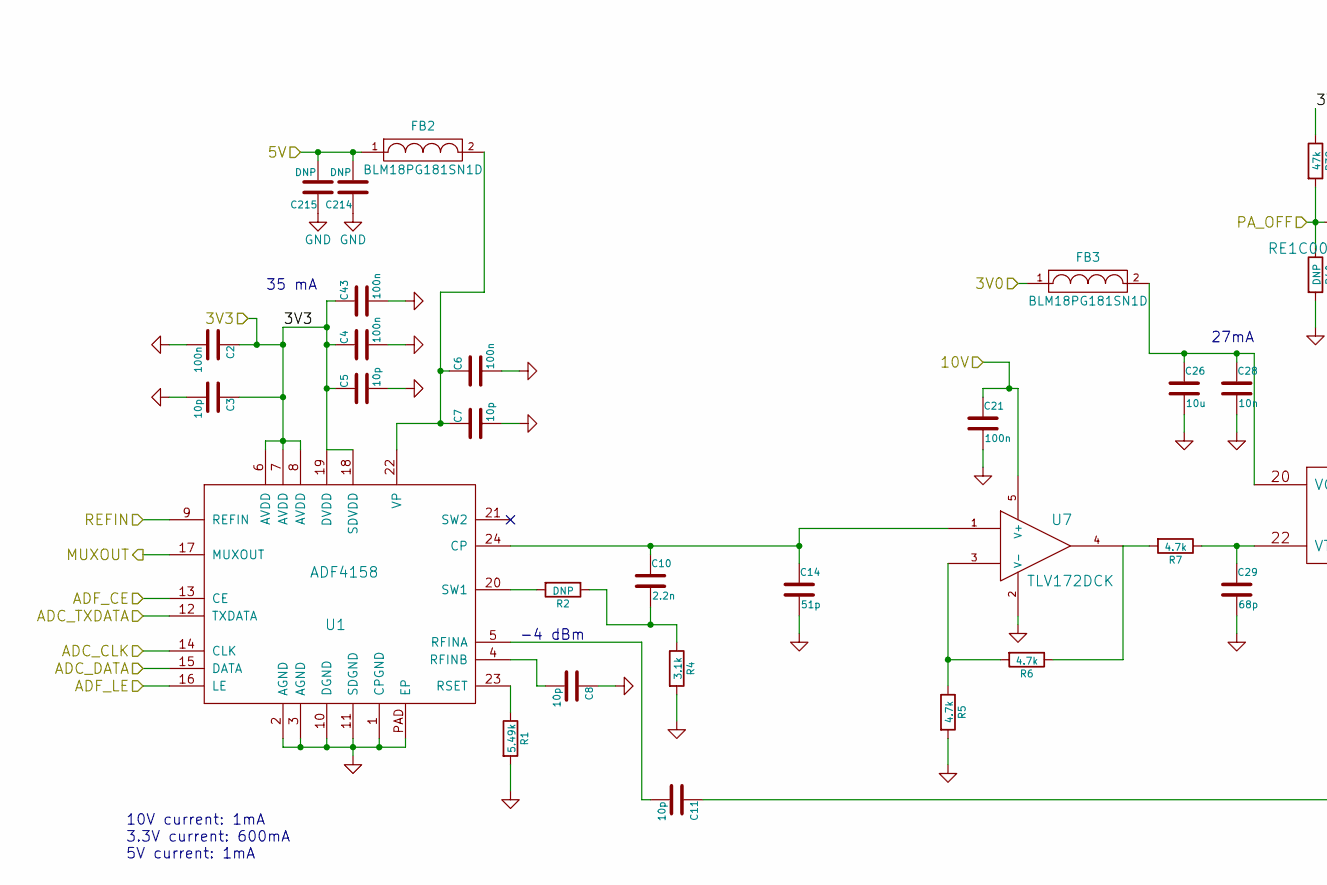
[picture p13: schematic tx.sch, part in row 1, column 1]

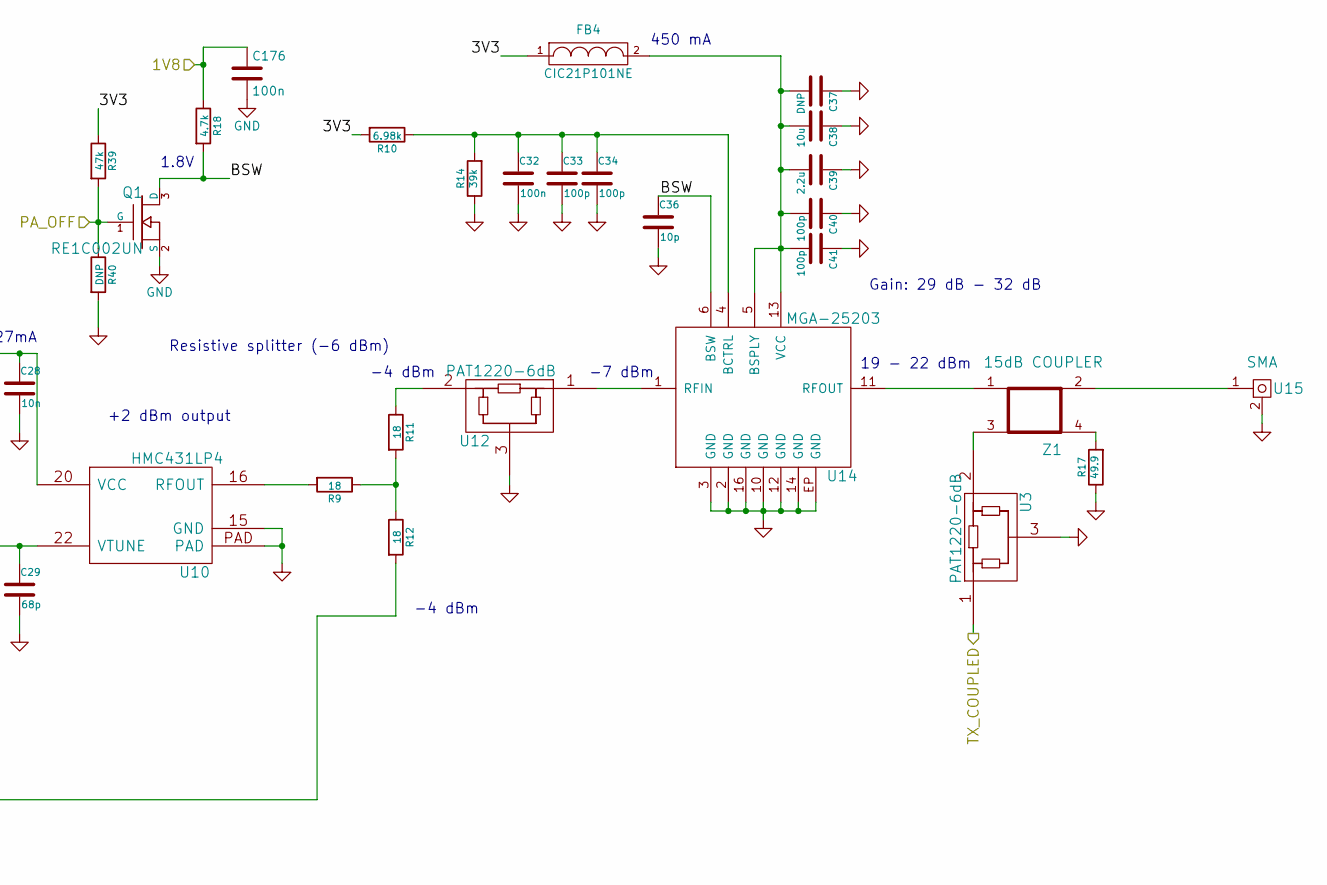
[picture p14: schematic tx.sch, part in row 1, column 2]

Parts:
C2, C4, C6, C21, C32, C43, C176: 100n; C_0402b
C3, C5, C7, C8, C11, C36: 10p; C_0402b
C10: 2.2n; C_0402b
C14: 51p; C_0402b
C26, C38: 10u; C_0805b
C28: 10n; C_0402b
C29: 68p; C_0402b
C33, C34, C40, C41: 100p; C_0402b
C37: DNP; C_0603b
C39: 2.2u; C_0603b
C214, C215: DNP; C_0805b
FB2, FB3: BLM18PG181SN1D; C_0603b
FB4: CIC21P101NE; C_0805b
Q1: RE1C002UN; SOT-416
R1: 5.49k; R_0402b
R2, R40: DNP; R_0402b
R4: 3.1k; R_0402b
R5, R6, R7, R18: 4.7k; R_0402b
R9, R11, R12: 18; R_0402b
R10: 6.98k; R_0402b
R14: 39k; R_0402b
R17: 49.9; R_0402b
R39: 47k; R_0402b
U1: ADF4158; VFQFN-24
U3, U12: PAT1220-6dB; PAT1220
U7: TLV172DCK; SOT-353_SC-70-5
U10: HMC431LP4; VQFN-24
U14: MGA-25203
U15: SMA; CONSMA003.062
Z1: 15dB COUPLER; coupler

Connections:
/1V8: C176.1, R18.1; also elsewhere on the board
/3V0: FB3.1; also elsewhere on the board
/3V3A: C2.1, C3.1, C4.1, C5.1, C43.1, FB4.1, R10.2, R39.1, U1.6 (AVDD), U1.7 (AVDD), U1.8 (AVDD), U1.18 (SDVDD), U1.19 (DVDD); also elsewhere on the board
/5V: C214.2, C215.2, FB2.1; also elsewhere on the board
/10V: C21.1, U7.5 (V+); also elsewhere on the board
/ADC_CE: U1.13 (CE); also elsewhere on the board
/ADF_CLK: U1.14 (CLK); also elsewhere on the board
/ADF_DATA: U1.15 (DATA); also elsewhere on the board
/ADF_LE: U1.16 (LE); also elsewhere on the board
/ADF_MUXOUT: U1.17 (MUXOUT); also elsewhere on the board
/ADF_REF: U1.9 (REFIN); also elsewhere on the board
/ADF_TXDATA: U1.12 (TXDATA); also elsewhere on the board
/LO: U3.1; also elsewhere on the board
/PA_OFF: Q1.1 (G), R39.2, R40.1; also elsewhere on the board
/tx/BSW: C36.1, Q1.3 (D), R18.2, U14.6 (BSW)
GND: C2.2, C3.2, C4.2, C5.2, C6.2, C7.2, C8.1, C14.2, C21.2, C26.2, C28.2, C29.2, C32.2, C33.2, C34.2, C36.2, C37.1, C38.1, C39.1, C40.1, C41.1, C43.2, C176.2, C214.1, C215.1, Q1.2 (S), R1.2, R4.2, R5.2, R14.1, R17.1, R40.2, U1.1 (CPGND), U1.2 (AGND), U1.3 (AGND), U1.10 (DGND), U1.11 (SDGND), U1.PAD (EP), U3.3, U7.2 (V-), U10.15 (GND), U10.PAD, U12.3, U14.2 (GND), U14.3 (GND), U14.10 (GND), U14.12 (GND), U14.14 (GND), U14.16 (GND), U14.EP (GND), U15.2; also elsewhere on the board
unnamed: C6.1, C7.1, FB2.2, U1.22 (VP)
unnamed: C8.2, U1.4 (RFINB)
unnamed: C10.1, C14.1, U1.24 (CP), U7.1
unnamed: C10.2, R2.1, R4.1
unnamed: C11.1, R12.2
unnamed: C11.2, U1.5 (RFINA)
unnamed: C26.1, C28.1, FB3.2, U10.20 (VCC)
unnamed: C29.1, R7.1, U10.22 (VTUNE)
unnamed: C32.1, C33.1, C34.1, R10.1, R14.2, U14.4 (BCTRL)
unnamed: C37.2, C38.2, C39.2, C40.2, C41.2, FB4.2, U14.5 (BSPLY), U14.13 (VCC)
unnamed: R1.1, U1.23 (RSET)
unnamed: R2.2, U1.20 (SW1)
unnamed: R5.1, R6.2, U7.3
unnamed: R6.1, R7.2, U7.4
unnamed: R9.2, U10.16 (RFOUT)
unnamed: R11.1, U12.2
unnamed: R9.1, R11.2, R12.1
unnamed: R17.2, Z1.4
unnamed: U3.2, Z1.3
unnamed: U12.1, U14.1 (RFIN)
unnamed: U14.11 (RFOUT), Z1.1
unnamed: U15.1, Z1.2

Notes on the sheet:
Resistive splitter (-6 dBm)
+2 dBm output
-4 dBm
27mA
-7 dBm
Gain: 29 dB - 32 dB
19 - 22 dBm
35 mA
450 mA
1.8V
10V current: 1mA 3.3V current: 600mA 5V current: 1mA

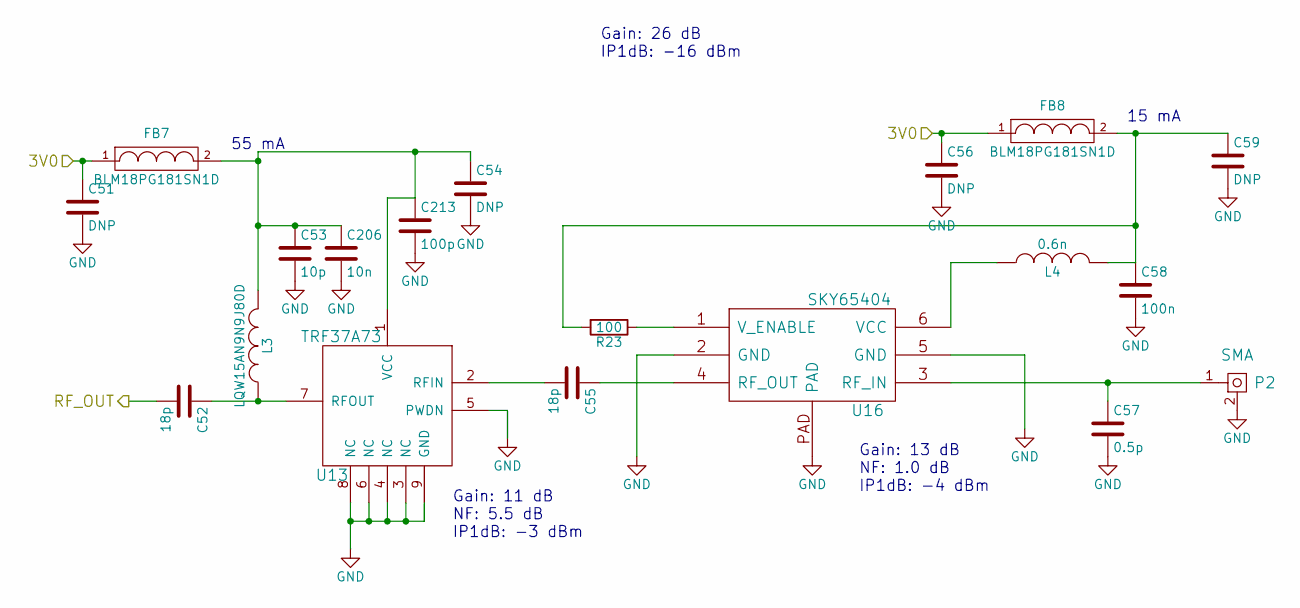
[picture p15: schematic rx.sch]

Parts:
C35, C47, C50, C54: DNP; C_0603b
C42, C46: 18p; C_0402b
C44: 10p; C_0402b
C48: 0.5p; C_0402b
C49: 100n; C_0402b
C179: 10n; C_0402b
C180: 100p; C_0402b
FB7, FB8: BLM18PG181SN1D; C_0603b
L1: LQW15AN9N9J80D; C_0402b
L2: 0.6n; C_0402b
P1: SMA; CONSMA003.062
R22: 100; R_0402b
U9: TRF37A73; DFN-8-1EP_2x2mm_Pitch0.5mm
U11: SKY65404; XFDFN-6

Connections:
/3V0: C35.1, C47.1, FB7.1, FB8.1; also elsewhere on the board
/RF1: C42.2; also elsewhere on the board
GND: C35.2, C44.2, C47.2, C48.2, C49.2, C50.2, C54.2, C179.2, C180.2, P1.2, U9.3 (NC), U9.4 (NC), U9.5 (PWDN), U9.6 (NC), U9.8 (NC), U9.9 (GND), U11.2 (GND), U11.5 (GND), U11.PAD; also elsewhere on the board
unnamed: C42.1, L1.1, U9.7 (RFOUT)
unnamed: C46.1, U11.4 (RF_OUT)
unnamed: C46.2, U9.2 (RFIN)
unnamed: C48.1, P1.1, U11.3 (RF_IN)
unnamed: L2.1, U11.6 (VCC)
unnamed: R22.1, U11.1 (V_ENABLE)

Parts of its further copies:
C45, C51, C56, C59: DNP; C_0603b
C52, C55: 18p; C_0402b
C53: 10p; C_0402b
C57: 0.5p; C_0402b
C58: 100n; C_0402b
C206: 10n; C_0402b
C213: 100p; C_0402b
FB5, FB6: BLM18PG181SN1D; C_0603b
L3: LQW15AN9N9J80D; C_0402b
L4: 0.6n; C_0402b
P2: SMA; CONSMA003.062
R23: 100; R_0402b
U13: TRF37A73; DFN-8-1EP_2x2mm_Pitch0.5mm
U16: SKY65404; XFDFN-6

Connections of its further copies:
/3V0: C51.1, C56.1, FB5.1, FB6.1; also elsewhere on the board
/RF2: C52.2; also elsewhere on the board
GND: C45.2, C51.2, C53.2, C56.2, C57.2, C58.2, C59.2, C206.2, C213.2, P2.2, U13.3 (NC), U13.4 (NC), U13.5 (PWDN), U13.6 (NC), U13.8 (NC), U13.9 (GND), U16.2 (GND), U16.5 (GND), U16.PAD; also elsewhere on the board
unnamed: C52.1, L3.1, U13.7 (RFOUT)
unnamed: C55.1, U16.4 (RF_OUT)
unnamed: C55.2, U13.2 (RFIN)
unnamed: C57.1, P2.1, U16.3 (RF_IN)
unnamed: L4.1, U16.6 (VCC)
unnamed: R23.1, U16.1 (V_ENABLE)

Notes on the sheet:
55 mA
15 mA
Gain: 13 dB NF: 1.0 dB IP1dB: -4 dBm
Gain: 11 dB NF: 5.5 dB IP1dB: -3 dBm
Gain: 26 dB IP1dB: -16 dBm

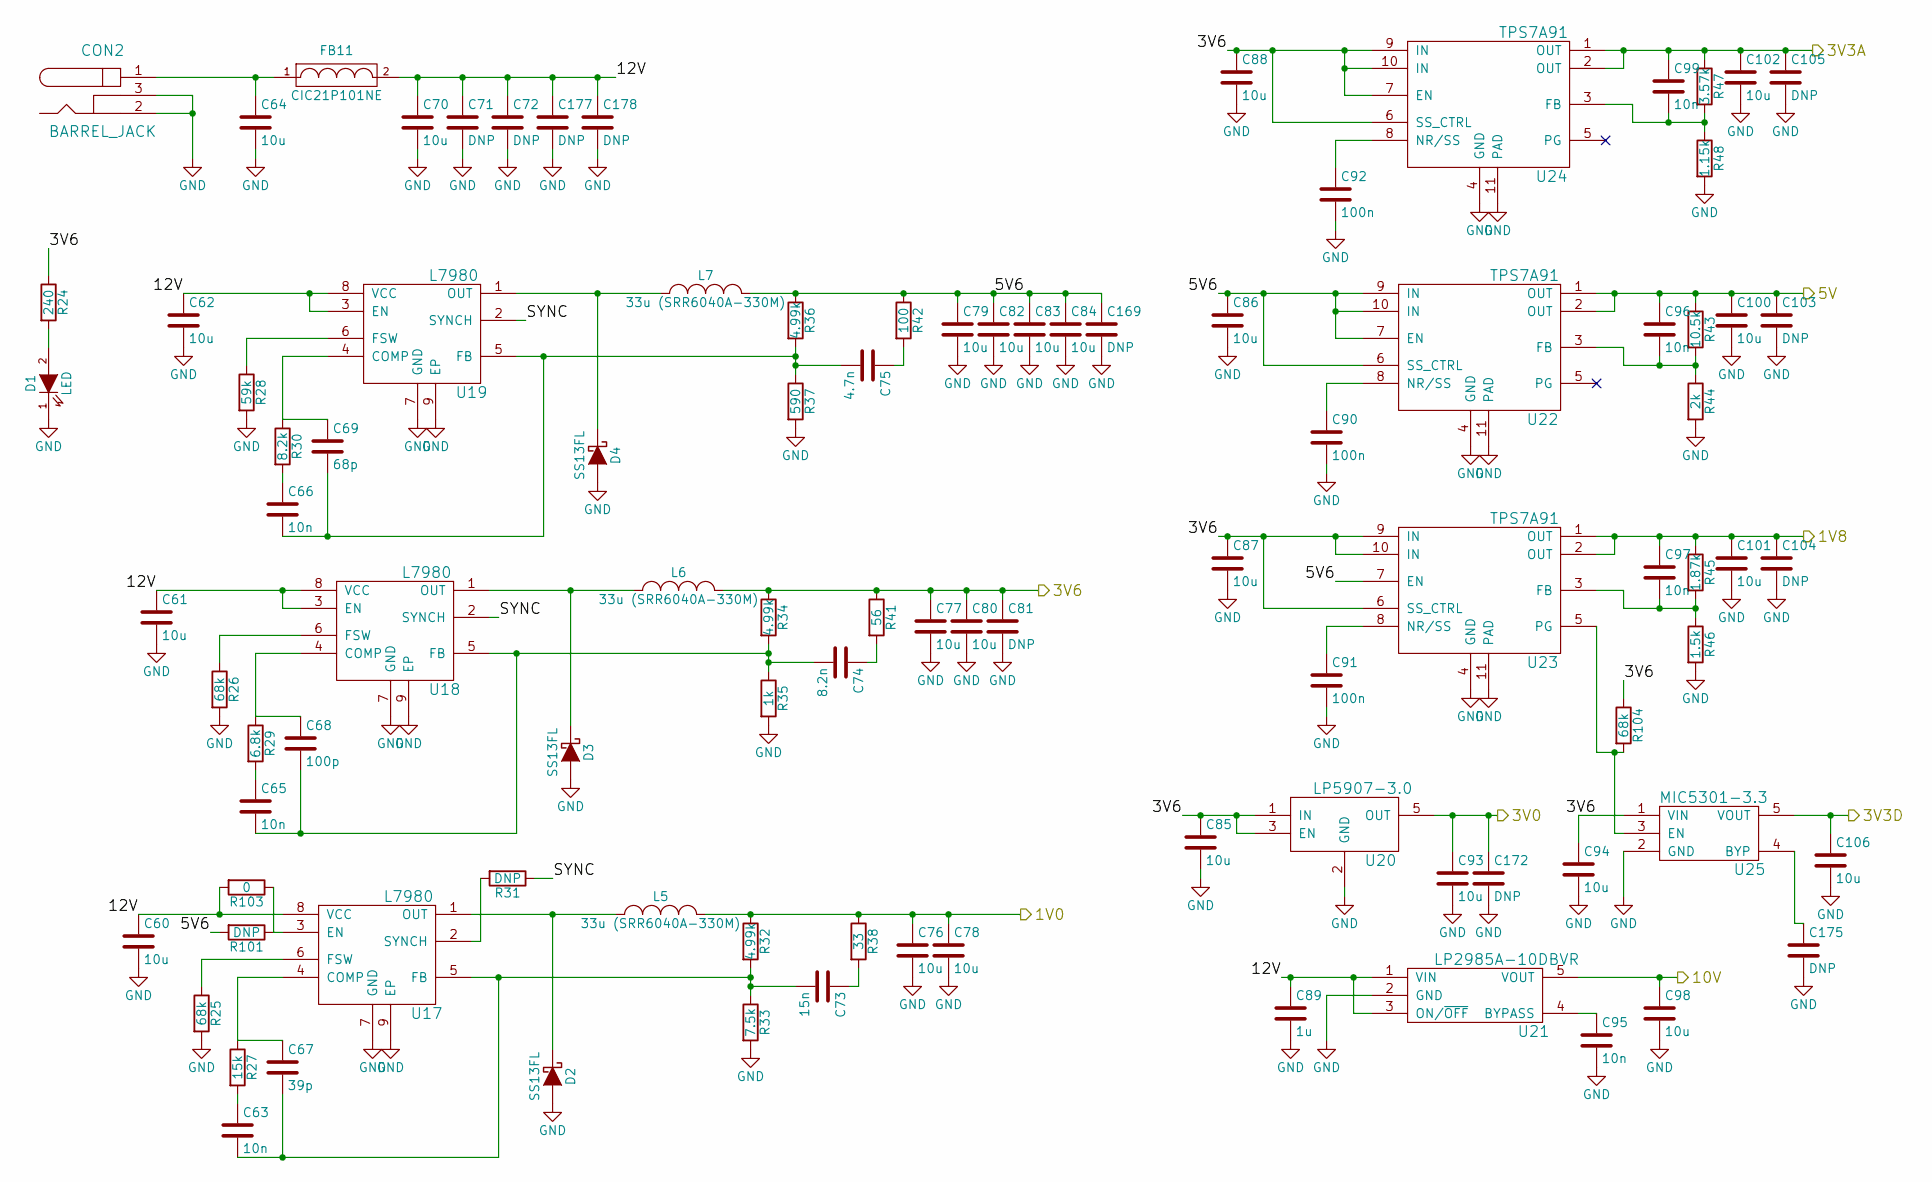
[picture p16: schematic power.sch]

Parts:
C60, C61, C62, C64, C70, C76, C77, C78, C79, C80, C82, C83, C84, C85, C86, C87, C88, C93, C94, C98, C100, C101, C102, C106: 10u; C_0805b
C63, C65, C66, C95, C96, C97, C99: 10n; C_0402b
C67: 39p; C_0402b
C68: 100p; C_0402b
C69: 68p; C_0402b
C71, C72, C81, C103, C104, C105, C169, C172, C177, C178: DNP; C_0805b
C73: 15n; C_0402b
C74: 8.2n; C_0402b
C75: 4.7n; C_0402b
C89: 1u; C_0603b
C90, C91, C92: 100n; C_0402b
C175: DNP; C_0402b
CON2: BARREL_JACK; EJ508A
D1: LED; LED_0603
D2, D3, D4: SS13FL; SOD-123F
FB11: CIC21P101NE; C_0805b
L5, L6, L7: 33u (SRR6040A-330M); SRR6040A
R24: 240; R_0402b
R25, R26, R104: 68k; R_0402b
R27: 15k; R_0402b
R28: 59k; R_0402b
R29: 6.8k; R_0402b
R30: 8.2k; R_0402b
R31, R101: DNP; R_0402b
R32, R34, R36: 4.99k; R_0402b
R33: 7.5k; R_0402b
R35: 1k; R_0402b
R37: 590; R_0402b
R38: 33; R_0402b
R41: 56; R_0402b
R42: 100; R_0402b
R43: 10.5k; R_0402b
R44: 2k; R_0402b
R45: 1.87k; R_0402b
R46: 1.5k; R_0402b
R47: 3.57k; R_0402b
R48: 1.15k; R_0402b
R103: 0; R_0402b
U17, U18, U19: L7980; DFN-8-1EP_3x3mm_Pitch0.5mm
U20: LP5907-3.0; SOT-23-5
U21: LP2985A-10DBVR; SOT-23-5
U22, U23, U24: TPS7A91; SON-10_2.5x2.5mm
U25: MIC5301-3.3; SOT-23-5

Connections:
/1V0: C76.1, C78.1, L5.2, R32.1, R38.1; also elsewhere on the board
/1V8: C97.1, C101.1, C104.1, R45.1, U23.1 (OUT), U23.2 (OUT); also elsewhere on the board
/3V0: C93.1, C172.1, U20.5 (OUT); also elsewhere on the board
/3V3A: C99.1, C102.1, C105.1, R47.1, U24.1 (OUT), U24.2 (OUT); also elsewhere on the board
/3V3D: C106.1, U25.5 (VOUT); also elsewhere on the board
/3V6: C77.1, C80.1, C81.1, C85.1, C87.1, C88.1, C94.1, L6.2, R24.1, R34.1, R41.1, R104.1, U20.1 (IN), U20.3 (EN), U23.6 (SS_CTRL), U23.9 (IN), U23.10 (IN), U24.6 (SS_CTRL), U24.7 (EN), U24.9 (IN), U24.10 (IN), U25.1 (VIN); also elsewhere on the board
/5V: C96.1, C100.1, C103.1, R43.1, U22.1 (OUT), U22.2 (OUT); also elsewhere on the board
/10V: C98.1, U21.5 (VOUT); also elsewhere on the board
/power/5V6: C79.1, C82.1, C83.1, C84.1, C86.1, C169.1, L7.2, R36.1, R42.1, R101.2, U22.6 (SS_CTRL), U22.7 (EN), U22.9 (IN), U22.10 (IN), U23.7 (EN)
/power/12V: C60.1, C61.1, C62.1, C70.1, C71.1, C72.1, C89.1, C177.1, C178.1, FB11.2, R103.2, U17.8 (VCC), U18.3 (EN), U18.8 (VCC), U19.3 (EN), U19.8 (VCC), U21.1 (VIN), U21.3 (ON/~OFF~)
/power/SYNC: R31.1, U18.2 (SYNCH), U19.2 (SYNCH)
GND: C60.2, C61.2, C62.2, C64.2, C70.2, C71.2, C72.2, C76.2, C77.2, C78.2, C79.2, C80.2, C81.2, C82.2, C83.2, C84.2, C85.2, C86.2, C87.2, C88.2, C89.2, C90.2, C91.2, C92.2, C93.2, C94.2, C95.2, C98.2, C100.2, C101.2, C102.2, C103.2, C104.2, C105.2, C106.2, C169.2, C172.2, C175.2, C177.2, C178.2, CON2.2, CON2.3, D1.1 (K), D2.2 (A), D3.2 (A), D4.2 (A), R25.2, R26.2, R28.2, R33.2, R35.2, R37.2, R44.2, R46.2, R48.2, U17.7 (GND), U17.9 (EP), U18.7 (GND), U18.9 (EP), U19.7 (GND), U19.9 (EP), U20.2 (GND), U21.2 (GND), U22.4 (GND), U22.11 (PAD), U23.4 (GND), U23.11 (PAD), U24.4 (GND), U24.11 (PAD), U25.2 (GND); also elsewhere on the board
unnamed: C63.1, R27.2
unnamed: C63.2, C67.2, C73.2, R32.2, R33.1, U17.5 (FB)
unnamed: C64.1, CON2.1, FB11.1
unnamed: C65.1, R29.2
unnamed: C65.2, C68.2, C74.2, R34.2, R35.1, U18.5 (FB)
unnamed: C66.1, R30.2
unnamed: C66.2, C69.2, C75.2, R36.2, R37.1, U19.5 (FB)
unnamed: C67.1, R27.1, U17.4 (COMP)
unnamed: C68.1, R29.1, U18.4 (COMP)
unnamed: C69.1, R30.1, U19.4 (COMP)
unnamed: C73.1, R38.2
unnamed: C74.1, R41.2
unnamed: C75.1, R42.2
unnamed: C90.1, U22.8 (NR/SS)
unnamed: C91.1, U23.8 (NR/SS)
unnamed: C92.1, U24.8 (NR/SS)
unnamed: C95.1, U21.4 (BYPASS)
unnamed: C96.2, R43.2, R44.1, U22.3 (FB)
unnamed: C97.2, R45.2, R46.1, U23.3 (FB)
unnamed: C99.2, R47.2, R48.1, U24.3 (FB)
unnamed: C175.1, U25.4 (BYP)
unnamed: D1.2 (A), R24.2
unnamed: D2.1 (K), L5.1, U17.1 (OUT)
unnamed: D3.1 (K), L6.1, U18.1 (OUT)
unnamed: D4.1 (K), L7.1, U19.1 (OUT)
unnamed: R25.1, U17.6 (FSW)
unnamed: R26.1, U18.6 (FSW)
unnamed: R28.1, U19.6 (FSW)
unnamed: R31.2, U17.2 (SYNCH)
unnamed: R101.1, R103.1, U17.3 (EN)
unnamed: R104.2, U23.5 (PG), U25.3 (EN)

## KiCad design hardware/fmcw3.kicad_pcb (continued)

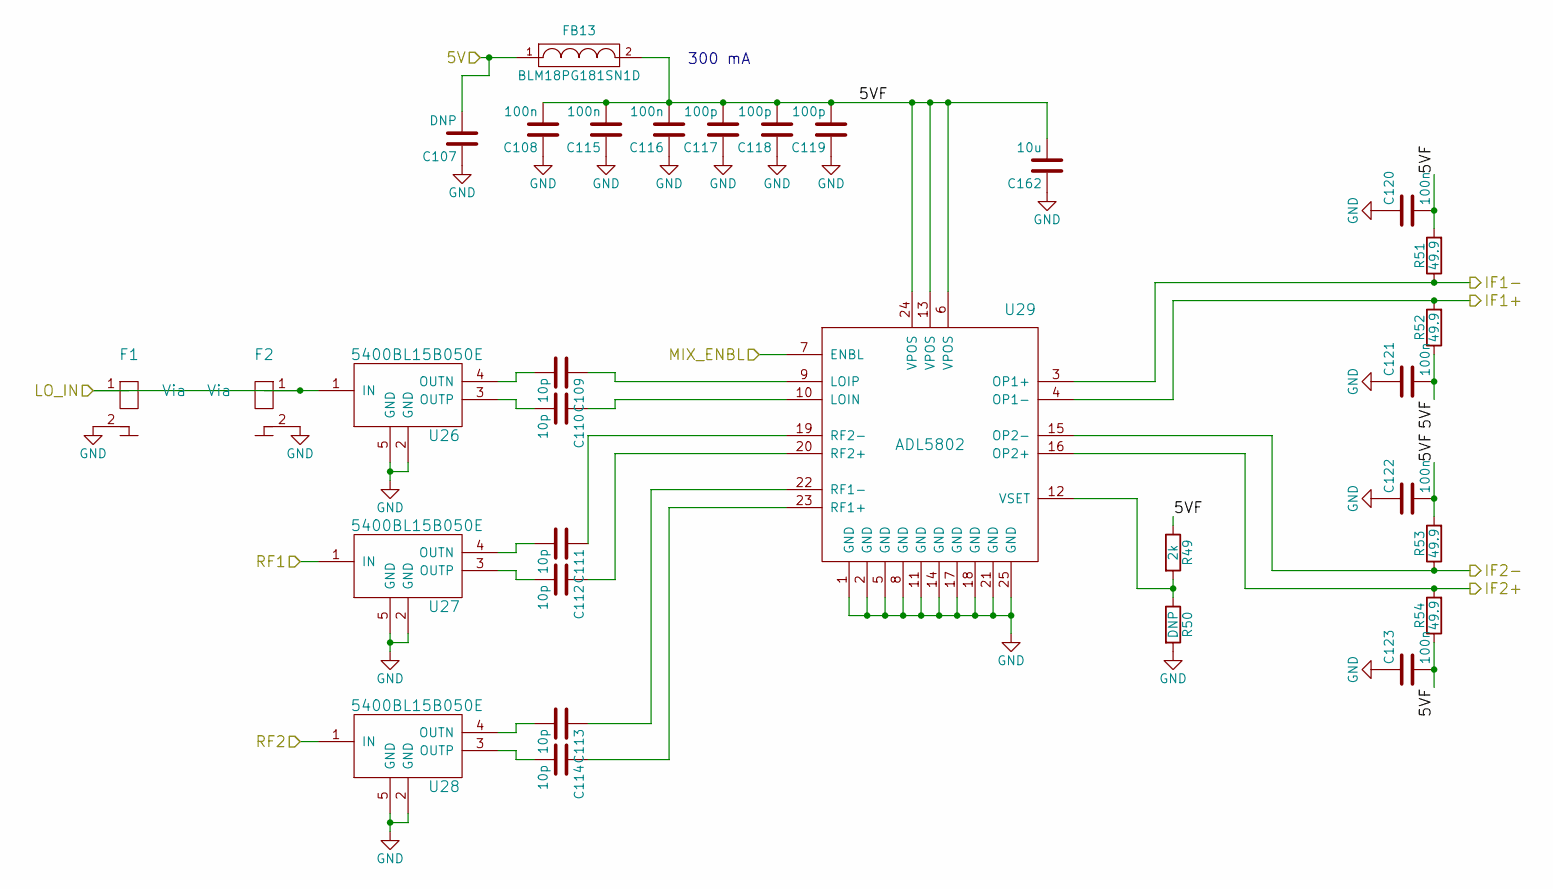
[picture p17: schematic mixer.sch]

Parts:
C107: DNP; C_0805b
C108, C115, C116, C120, C121, C122, C123: 100n; C_0402b
C109, C110, C111, C112, C113, C114: 10p; C_0402b
C117, C118, C119: 100p; C_0402b
C162: 10u; C_0805b
F1, F2: Via; RF_via
FB13: BLM18PG181SN1D; C_0603b
R49: 2k; R_0402b
R50: DNP; R_0402b
R51, R52, R53, R54: 49.9; R_0402b
U26, U27, U28: 5400BL15B050E
U29: ADL5802; QFN-24-1EP_4x4mm_Pitch0.5mm

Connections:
/5V: C107.2, FB13.1; also elsewhere on the board
/LO: F1.1, F2.1, U26.1 (IN); also elsewhere on the board
/MIX_ENBL: U29.7 (ENBL); also elsewhere on the board
/RF1: U27.1 (IN); also elsewhere on the board
/RF2: U28.1 (IN); also elsewhere on the board
/if/IF1+: R52.2, U29.4 (OP1-); also elsewhere on the board
/if/IF1-: R51.1, U29.3 (OP1+); also elsewhere on the board
/if/IF2+: R54.2, U29.16 (OP2+); also elsewhere on the board
/if/IF2-: R53.1, U29.15 (OP2-); also elsewhere on the board
/mixer/5VF: C108.2, C115.2, C116.2, C117.2, C118.2, C119.2, C120.2, C121.2, C122.2, C123.2, C162.2, FB13.2, R49.1, R51.2, R52.1, R53.2, R54.1, U29.6 (VPOS), U29.13 (VPOS), U29.24 (VPOS)
GND: C107.1, C108.1, C115.1, C116.1, C117.1, C118.1, C119.1, C120.1, C121.1, C122.1, C123.1, C162.1, F1.2, F2.2, R50.2, U26.2 (GND), U26.5 (GND), U27.2 (GND), U27.5 (GND), U28.2 (GND), U28.5 (GND), U29.1 (GND), U29.2 (GND), U29.5 (GND), U29.8 (GND), U29.11 (GND), U29.14 (GND), U29.17 (GND), U29.18 (GND), U29.21 (GND), U29.25 (GND); also elsewhere on the board
unnamed: C109.1, U29.9 (LOIP)
unnamed: C109.2, U26.4 (OUTN)
unnamed: C110.1, U29.10 (LOIN)
unnamed: C110.2, U26.3 (OUTP)
unnamed: C111.1, U29.19 (RF2-)
unnamed: C111.2, U27.4 (OUTN)
unnamed: C112.1, U29.20 (RF2+)
unnamed: C112.2, U27.3 (OUTP)
unnamed: C113.1, U29.22 (RF1-)
unnamed: C113.2, U28.4 (OUTN)
unnamed: C114.1, U29.23 (RF1+)
unnamed: C114.2, U28.3 (OUTP)
unnamed: R49.2, R50.1, U29.12 (VSET)

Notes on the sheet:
300 mA

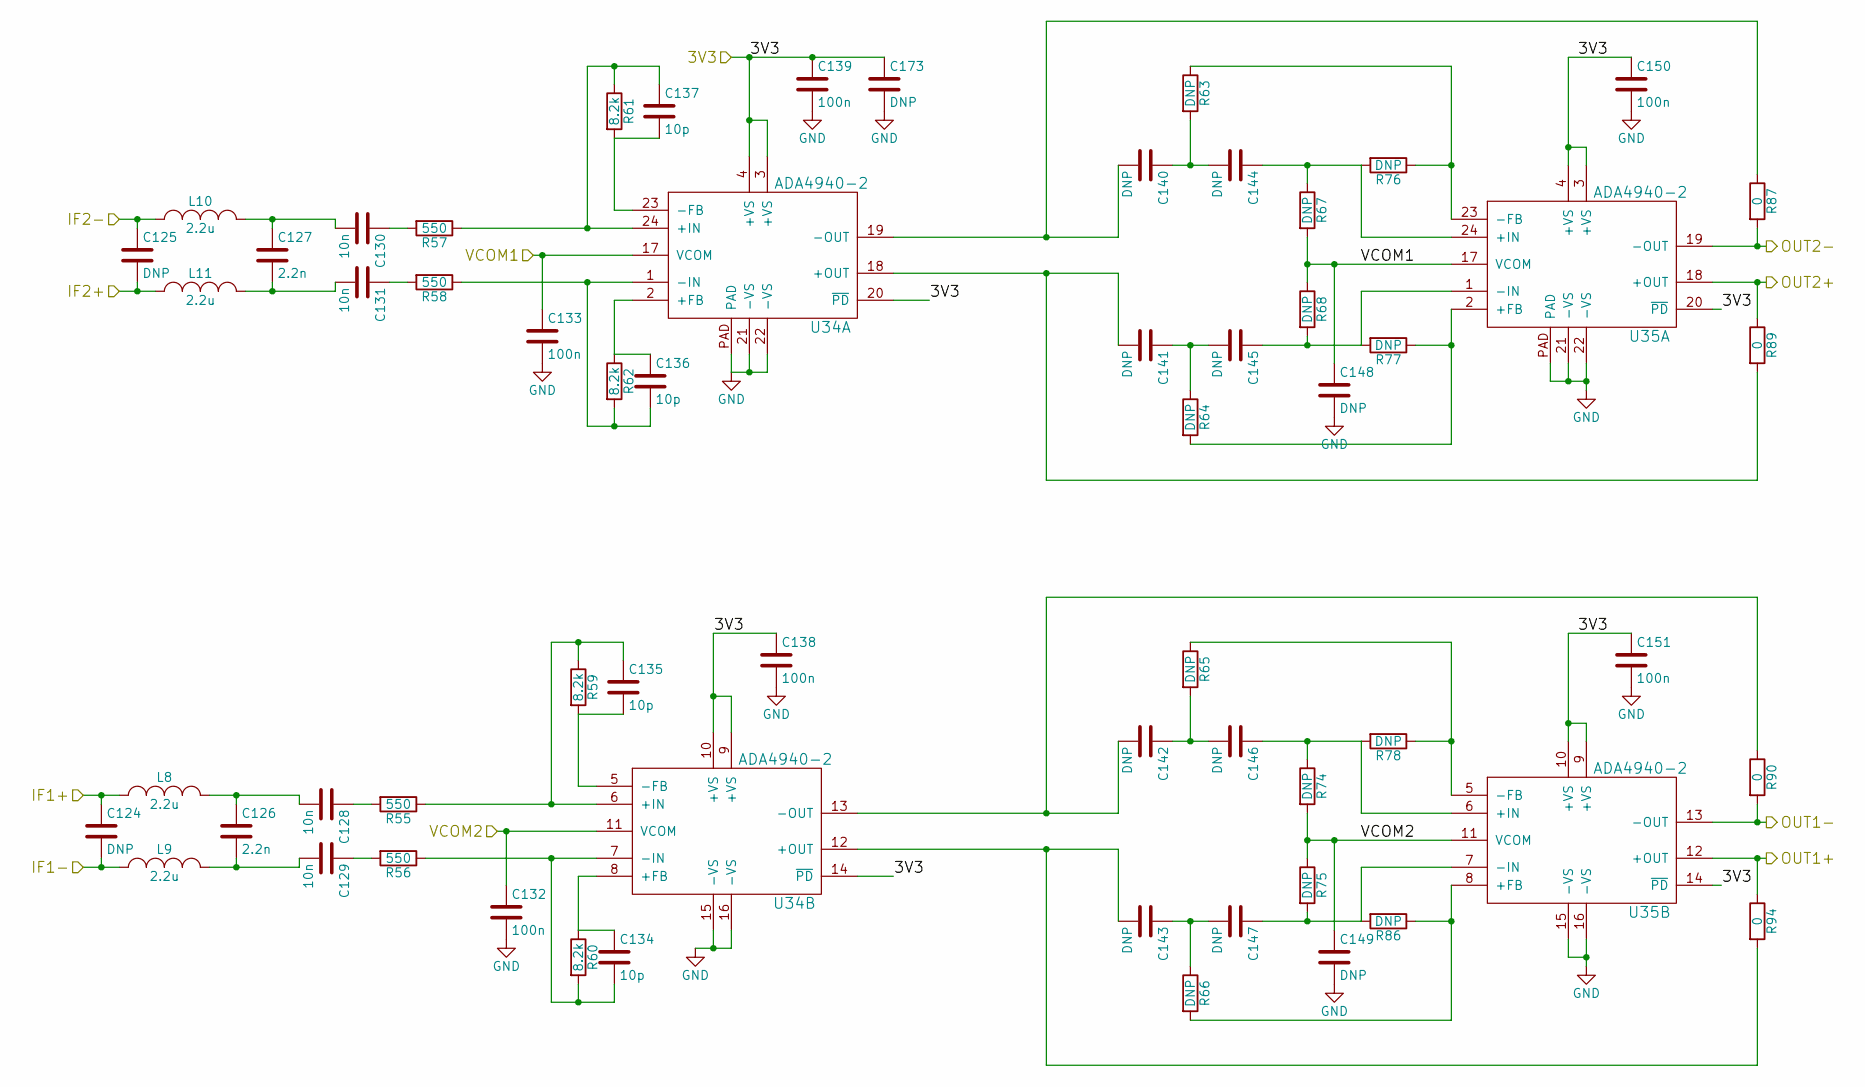
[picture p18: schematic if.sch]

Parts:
C124, C125, C140, C141, C142, C143, C144, C145, C146, C147, C148, C149: DNP; C_0402b
C126, C127: 2.2n; C_0402b
C128, C129, C130, C131: 10n; C_0402b
C132, C133, C138, C139, C150, C151: 100n; C_0402b
C134, C135, C136, C137: 10p; C_0402b
C173: DNP; C_0805b
L8, L9, L10, L11: 2.2u; C_0805b
R55, R56, R57, R58: 550; R_0402b
R59, R60, R61, R62: 8.2k; R_0402b
R63, R64, R65, R66, R67, R68, R74, R75, R76, R77, R78, R86: DNP; R_0402b
R87, R89, R90, R94: 0; R_0402b
U34, U35: ADA4940-2; VFQFN-24

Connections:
/3V3A: C138.1, C139.1, C150.1, C151.1, C173.1, U34.3 (+VS), U34.4 (+VS), U34.9 (+VS), U34.10 (+VS), U34.14 (~PD), U34.20 (~PD), U35.3 (+VS), U35.4 (+VS), U35.9 (+VS), U35.10 (+VS), U35.14 (~PD), U35.20 (~PD); also elsewhere on the board
/ADC1+: R94.1, U35.12 (+OUT); also elsewhere on the board
/ADC1-: R90.2, U35.13 (-OUT); also elsewhere on the board
/ADC2+: R89.1, U35.18 (+OUT); also elsewhere on the board
/ADC2-: R87.2, U35.19 (-OUT); also elsewhere on the board
/ADC_VCM1: C133.1, C148.1, R67.2, R68.1, U34.17 (VCOM), U35.17 (VCOM); also elsewhere on the board
/ADC_VCM2: C132.1, C149.1, R74.2, R75.1, U34.11 (VCOM), U35.11 (VCOM); also elsewhere on the board
/if/IF1+: C124.1, L8.1; also elsewhere on the board
/if/IF1-: C124.2, L9.1; also elsewhere on the board
/if/IF2+: C125.2, L11.1; also elsewhere on the board
/if/IF2-: C125.1, L10.1; also elsewhere on the board
GND: C132.2, C133.2, C138.2, C139.2, C148.2, C149.2, C150.2, C151.2, C173.2, U34.15 (-VS), U34.16 (-VS), U34.21 (-VS), U34.22 (-VS), U34.PAD, U35.15 (-VS), U35.16 (-VS), U35.21 (-VS), U35.22 (-VS), U35.PAD; also elsewhere on the board
unnamed: C126.1, C128.2, L8.2
unnamed: C126.2, C129.2, L9.2
unnamed: C127.1, C130.2, L10.2
unnamed: C127.2, C131.2, L11.2
unnamed: C128.1, R55.2
unnamed: C129.1, R56.2
unnamed: C130.1, R57.2
unnamed: C131.1, R58.2
unnamed: C134.1, R60.1, U34.8 (+FB)
unnamed: C134.2, R56.1, R60.2, U34.7 (-IN)
unnamed: C135.1, R55.1, R59.1, U34.6 (+IN)
unnamed: C135.2, R59.2, U34.5 (-FB)
unnamed: C136.1, R62.1, U34.2 (+FB)
unnamed: C136.2, R58.1, R62.2, U34.1 (-IN)
unnamed: C137.1, R57.1, R61.1, U34.24 (+IN)
unnamed: C137.2, R61.2, U34.23 (-FB)
unnamed: C140.1, C144.2, R63.2
unnamed: C140.2, R87.1, U34.19 (-OUT)
unnamed: C141.1, C145.2, R64.1
unnamed: C141.2, R89.2, U34.18 (+OUT)
unnamed: C142.1, C146.2, R65.2
unnamed: C142.2, R90.1, U34.13 (-OUT)
unnamed: C143.1, C147.2, R66.1
unnamed: C143.2, R94.2, U34.12 (+OUT)
unnamed: C144.1, R67.1, R76.2, U35.24 (+IN)
unnamed: C145.1, R68.2, R77.2, U35.1 (-IN)
unnamed: C146.1, R74.1, R78.2, U35.6 (+IN)
unnamed: C147.1, R75.2, R86.2, U35.7 (-IN)
unnamed: R63.1, R76.1, U35.23 (-FB)
unnamed: R64.2, R77.1, U35.2 (+FB)
unnamed: R65.1, R78.1, U35.5 (-FB)
unnamed: R66.2, R86.1, U35.8 (+FB)

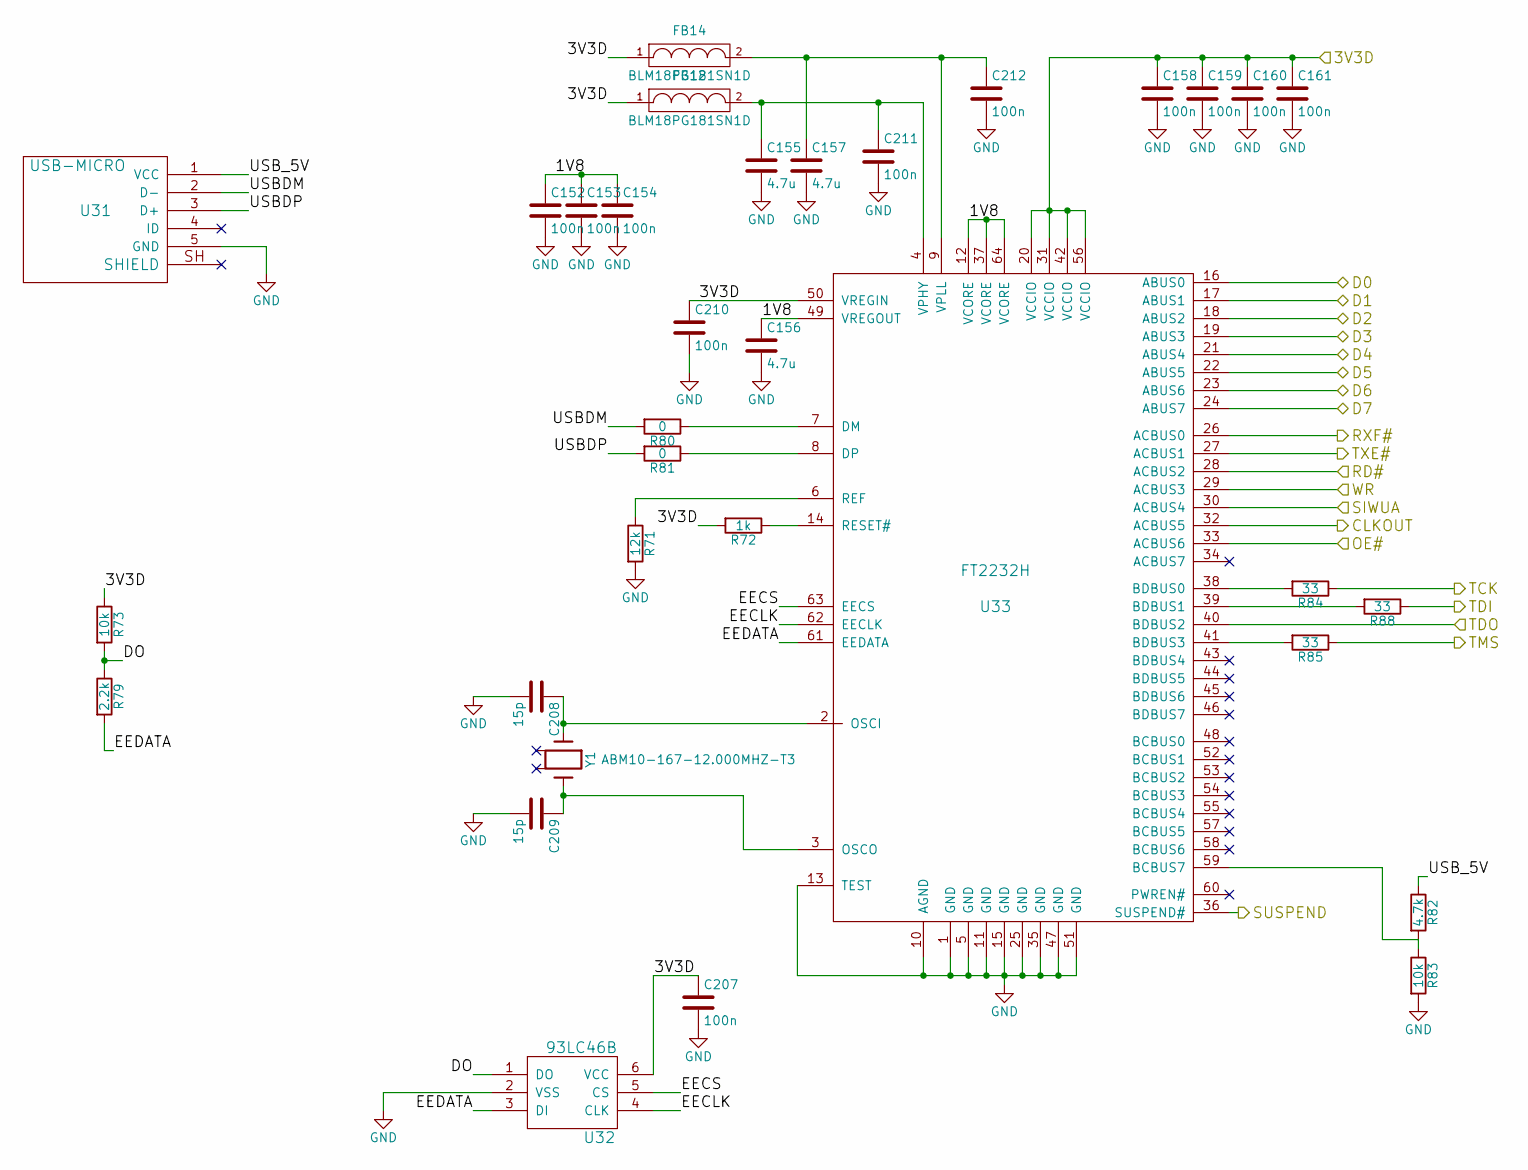
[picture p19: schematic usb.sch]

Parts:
C152, C153, C154, C158, C159, C160, C161, C207, C210, C211, C212: 100n; C_0402b
C155, C156, C157: 4.7u; C_0603b
C208, C209: 15p; C_0402b
FB12, FB14: BLM18PG181SN1D; C_0603b
R71: 12k; R_0402b
R72: 1k; R_0402b
R73, R83: 10k; R_0402b
R79: 2.2k; R_0402b
R80, R81: 0; R_0402b
R82: 4.7k; R_0402b
R84, R85, R88: 33; R_0402b
U31: USB-MICRO; USB_MICRO
U32: 93LC46B; SOT-23-6
U33: FT2232H; LQFP-64_10x10mm_Pitch0.5mm
Y1: ABM10-167-12.000MHZ-T3; ABM10

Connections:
/3V3D: C158.1, C159.1, C160.1, C161.1, C207.1, C210.1, FB12.1, FB14.1, R72.2, R73.1, U32.6 (VCC), U33.20 (VCCIO), U33.31 (VCCIO), U33.42 (VCCIO), U33.50 (VREGIN), U33.56 (VCCIO); also elsewhere on the board
/fpga/CLKOUT: U33.32 (ACBUS5); also elsewhere on the board
/fpga/FT_D0: U33.16 (ABUS0); also elsewhere on the board
/fpga/FT_D1: U33.17 (ABUS1); also elsewhere on the board
/fpga/FT_D2: U33.18 (ABUS2); also elsewhere on the board
/fpga/FT_D3: U33.19 (ABUS3); also elsewhere on the board
/fpga/FT_D4: U33.21 (ABUS4); also elsewhere on the board
/fpga/FT_D5: U33.22 (ABUS5); also elsewhere on the board
/fpga/FT_D6: U33.23 (ABUS6); also elsewhere on the board
/fpga/FT_D7: U33.24 (ABUS7); also elsewhere on the board
/fpga/FT_SUSPEND: U33.36 (SUSPEND#); also elsewhere on the board
/fpga/OE#: U33.33 (ACBUS6); also elsewhere on the board
/fpga/RD#: U33.28 (ACBUS2); also elsewhere on the board
/fpga/RXF#: U33.26 (ACBUS0); also elsewhere on the board
/fpga/SIWUA: U33.30 (ACBUS4); also elsewhere on the board
/fpga/TCK: R84.1; also elsewhere on the board
/fpga/TDI: R88.1; also elsewhere on the board
/fpga/TDO: U33.40 (BDBUS2); also elsewhere on the board
/fpga/TMS: R85.1; also elsewhere on the board
/fpga/TXE#: U33.27 (ACBUS1); also elsewhere on the board
/fpga/WR: U33.29 (ACBUS3); also elsewhere on the board
/fpga/usb/1V8: C152.1, C153.1, C154.1, C156.1, U33.12 (VCORE), U33.37 (VCORE), U33.49 (VREGOUT), U33.64 (VCORE)
/fpga/usb/DO: R73.2, R79.1, U32.1 (DO)
/fpga/usb/EECLK: U32.4 (CLK), U33.62 (EECLK)
/fpga/usb/EECS: U32.5 (CS), U33.63 (EECS)
/fpga/usb/EEDATA: R79.2, U32.3 (DI), U33.61 (EEDATA)
/fpga/usb/USBDM: R80.2, U31.2 (D-)
/fpga/usb/USBDP: R81.2, U31.3 (D+)
/fpga/usb/USB_5V: R82.1, U31.1 (VCC)
GND: C152.2, C153.2, C154.2, C155.2, C156.2, C157.2, C158.2, C159.2, C160.2, C161.2, C207.2, C208.2, C209.2, C210.2, C211.2, C212.2, R71.2, R83.2, U31.5 (GND), U32.2 (VSS), U33.1 (GND), U33.5 (GND), U33.10 (AGND), U33.11 (GND), U33.13 (TEST), U33.15 (GND), U33.25 (GND), U33.35 (GND), U33.47 (GND), U33.51 (GND); also elsewhere on the board
unnamed: C155.1, C211.1, FB12.2, U33.4 (VPHY)
unnamed: C157.1, C212.1, FB14.2, U33.9 (VPLL)
unnamed: C208.1, U33.2 (OSCI), Y1.1
unnamed: C209.1, U33.3 (OSCO), Y1.3
unnamed: R71.1, U33.6 (REF)
unnamed: R72.1, U33.14 (RESET#)
unnamed: R80.1, U33.7 (DM)
unnamed: R81.1, U33.8 (DP)
unnamed: R82.2, R83.1, U33.59 (BCBUS7)
unnamed: R84.2, U33.38 (BDBUS0)
unnamed: R85.2, U33.41 (BDBUS3)
unnamed: R88.2, U33.39 (BDBUS1)

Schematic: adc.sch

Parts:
C19, C20, C217, C218, C222, C249: 1u; C_0603b
C22, C31, C216, C220: 2.2u; C_0603b
C23, C24, C25, C27, C30, C219, C221, C223, C224, C225: 100n; C_0402b
C163, C164, C165, C166, C167, C168: 100p; C_0402b
C248: 10u; C_0805b
R20, R91, R93: 0; R_0402b
R21: 22; R_0402b
R92: DNP; R_0402b
R97, R98, R99, R100: 49.9; R_0402b
U8: LTC2292; QFN-64-1EP_9x9mm_Pitch0.5mm
U39: LP5907-3.0; SOT-23-5

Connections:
/3V3D: C25.1, C225.1, U8.32 (OVDD), U8.49 (OVDD); also elsewhere on the board
/3V6: C248.1, U39.1 (IN), U39.3 (EN); also elsewhere on the board
/ADC1+: R100.2; also elsewhere on the board
/ADC1-: R98.2; also elsewhere on the board
/ADC2+: R99.2; also elsewhere on the board
/ADC2-: R97.2; also elsewhere on the board
/ADC_REF: R21.2, U8.8 (CLKA), U8.9 (CLKB); also elsewhere on the board
/ADC_VCM1: C216.1, C219.1, U8.61 (VCMA); also elsewhere on the board
/ADC_VCM2: C30.1, C31.1, U8.20 (VCMB); also elsewhere on the board
/fpga/ADC_OE1: U8.58 (~OEA); also elsewhere on the board
/fpga/ADC_OE2: U8.23 (~OEB); also elsewhere on the board
/fpga/ADC_SHDN1: U8.59 (SHDNA); also elsewhere on the board
/fpga/ADC_SHDN2: U8.22 (SHDNB); also elsewhere on the board
/fpga/D0: U8.43 (DA0); also elsewhere on the board
/fpga/D1: U8.44 (DA1); also elsewhere on the board
/fpga/D2: U8.45 (DA2); also elsewhere on the board
/fpga/D3: U8.46 (DA3); also elsewhere on the board
/fpga/D4: U8.47 (DA4); also elsewhere on the board
/fpga/D5: U8.48 (DA5); also elsewhere on the board
/fpga/D6: U8.51 (DA6); also elsewhere on the board
/fpga/D7: U8.52 (DA7); also elsewhere on the board
/fpga/D8: U8.53 (DA8); also elsewhere on the board
/fpga/D9: U8.54 (DA9); also elsewhere on the board
/fpga/D10: U8.55 (DA10); also elsewhere on the board
/fpga/D11: U8.56 (DA11); also elsewhere on the board
/fpga/OF1: U8.57 (OFA); also elsewhere on the board
/fpga/OF2: U8.40 (OFB); also elsewhere on the board
/fpga/adc/3V0: C24.1, C27.1, C222.1, C223.1, C224.1, C249.1, R20.2, R91.1, R93.2, U8.7 (VDD), U8.10 (VDD), U8.18 (VDD), U8.63 (VDD), U39.5 (OUT)
/fpga/adc/REFHA: C217.1, C220.1, C221.1, U8.3 (REFHA), U8.4 (REFHA)
/fpga/adc/REFHB: C19.1, C22.1, C23.1, U8.11 (REFLB), U8.12 (REFLB)
/fpga/adc/REFLA: C218.1, C220.2, C221.2, U8.5 (REFLA), U8.6 (REFLA)
/fpga/adc/REFLB: C20.1, C22.2, C23.2, U8.13 (REFHB), U8.14 (REFHB)
GND: C19.2, C20.2, C24.2, C25.2, C27.2, C30.2, C31.2, C163.1, C165.2, C166.1, C168.2, C216.2, C217.2, C218.2, C219.2, C222.2, C223.2, C224.2, C225.2, C248.2, C249.2, R92.2, U8.17 (GND), U8.31 (OGND), U8.50 (OGND), U8.64 (GND), U8.65 (PAD), U39.2 (GND); also elsewhere on the board
unnamed: C163.2, C164.1, R97.1, U8.1 (AINA+)
unnamed: C164.2, C165.1, R99.1, U8.2 (AINA-)
unnamed: C166.2, C167.1, R98.1, U8.15 (AINB-)
unnamed: C167.2, C168.1, R100.1, U8.16 (AINB+)
unnamed: R20.1, U8.19 (SENSEB)
unnamed: R21.1, U8.21 (MUX)
unnamed: R91.2, R92.1, U8.60 (MODE)
unnamed: R93.1, U8.62 (SENSEA)

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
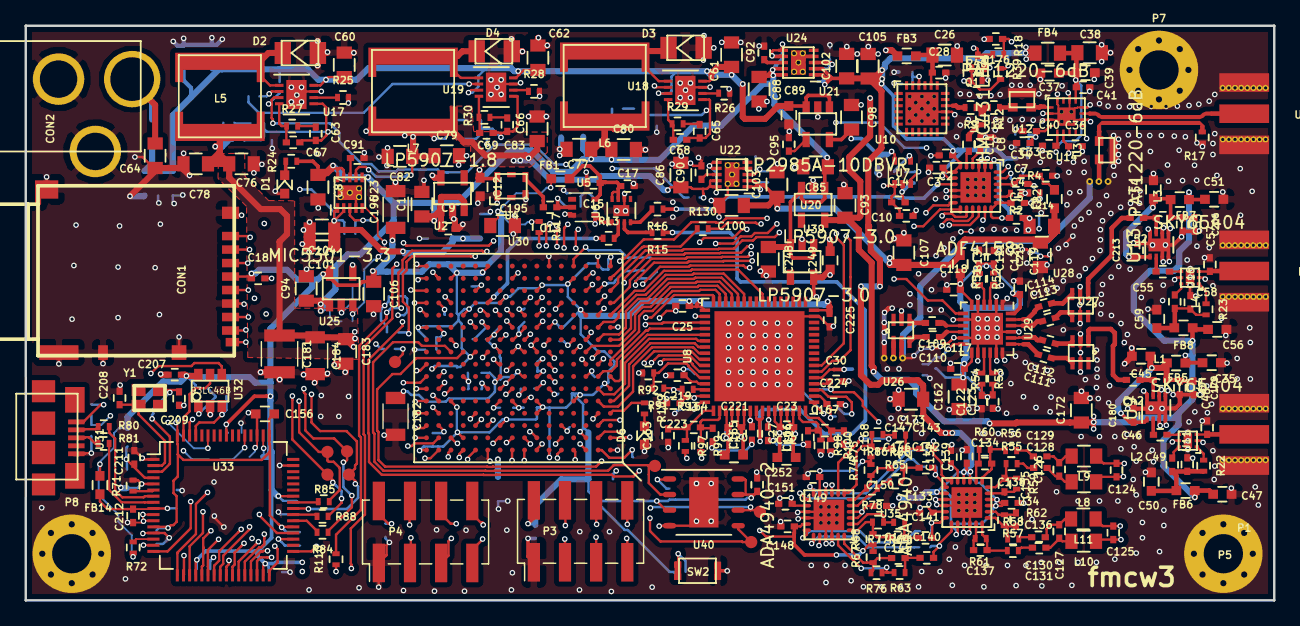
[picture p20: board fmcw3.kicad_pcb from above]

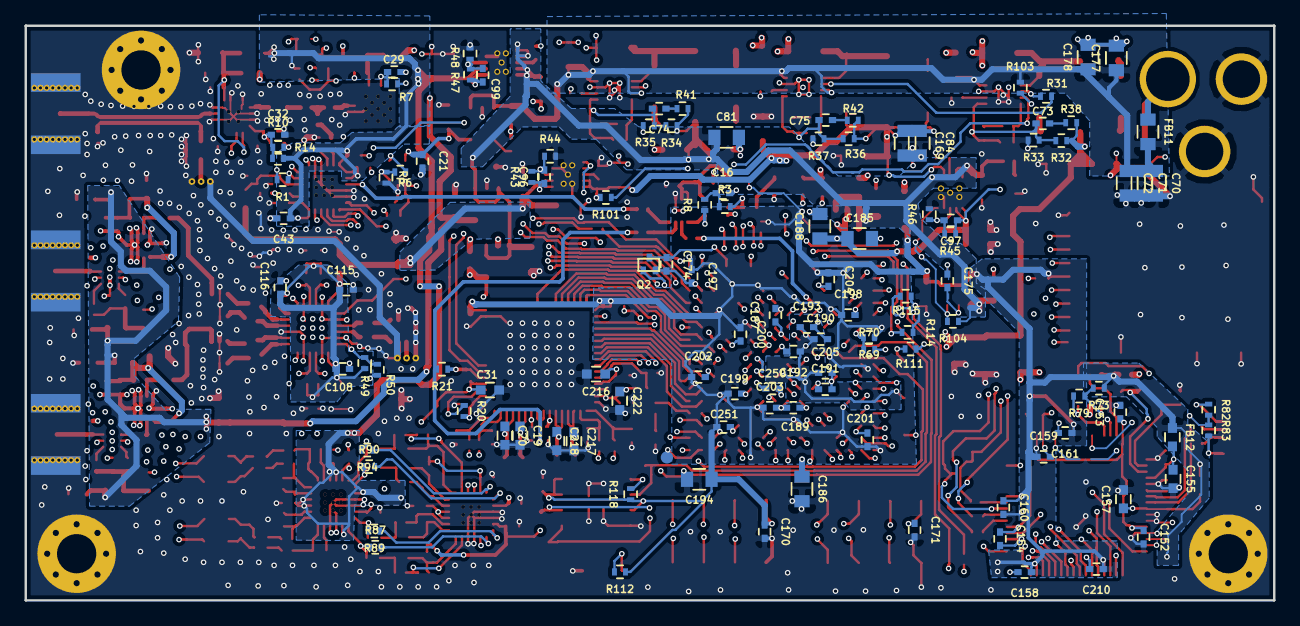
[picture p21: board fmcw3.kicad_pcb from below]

Board: 4 copper layers, 101.8 x 46.8 mm, 429 parts (114 on the bottom side), 267 nets.

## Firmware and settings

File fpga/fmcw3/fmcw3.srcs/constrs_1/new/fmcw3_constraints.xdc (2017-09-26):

create_clock -period 25.000 -name clk -waveform {0.000 12.500} [get_ports clk]
create_clock -period 16.667 -name ft_clkout -waveform {0.000 8.333} [get_ports ft_clkout]

set_property CLOCK_DEDICATED_ROUTE FALSE [get_nets ft_clkout_IBUF]

set_property CFGBVS VCCO [current_design]
set_property CONFIG_VOLTAGE 3.3 [current_design]

set_property IOSTANDARD LVCMOS33 [get_ports {clk}]

set_property IOSTANDARD LVCMOS33 [get_ports {adc_d[11]}]
set_property IOSTANDARD LVCMOS33 [get_ports {adc_d[10]}]
set_property IOSTANDARD LVCMOS33 [get_ports {adc_d[9]}]
set_property IOSTANDARD LVCMOS33 [get_ports {adc_d[8]}]
set_property IOSTANDARD LVCMOS33 [get_ports {adc_d[7]}]
set_property IOSTANDARD LVCMOS33 [get_ports {adc_d[6]}]
set_property IOSTANDARD LVCMOS33 [get_ports {adc_d[5]}]
set_property IOSTANDARD LVCMOS33 [get_ports {adc_d[4]}]
set_property IOSTANDARD LVCMOS33 [get_ports {adc_d[3]}]
set_property IOSTANDARD LVCMOS33 [get_ports {adc_d[2]}]
set_property IOSTANDARD LVCMOS33 [get_ports {adc_d[1]}]
set_property IOSTANDARD LVCMOS33 [get_ports {adc_d[0]}]

set_property IOSTANDARD LVCMOS33 [get_ports {adc_shdn[0]}]
set_property IOSTANDARD LVCMOS33 [get_ports {adc_shdn[1]}]
set_property IOSTANDARD LVCMOS33 [get_ports {adc_oe[0]}]
set_property IOSTANDARD LVCMOS33 [get_ports {adc_oe[1]}]
set_property IOSTANDARD LVCMOS33 [get_ports {adc_of[0]}]
set_property IOSTANDARD LVCMOS33 [get_ports {adc_of[1]}]

set_property IOSTANDARD LVCMOS33 [get_ports {mix_enbl}]
set_property IOSTANDARD LVCMOS33 [get_ports {pa_off}]

set_property IOSTANDARD LVCMOS33 [get_ports {adf_muxout}]
set_property IOSTANDARD LVCMOS33 [get_ports {adf_le}]
set_property IOSTANDARD LVCMOS33 [get_ports {adf_ce}]
set_property IOSTANDARD LVCMOS33 [get_ports {adf_le}]
set_property IOSTANDARD LVCMOS33 [get_ports {adf_data}]
set_property IOSTANDARD LVCMOS33 [get_ports {adf_clk}]
set_property IOSTANDARD LVCMOS33 [get_ports {adf_txdata}]
set_property IOSTANDARD LVCMOS33 [get_ports {adf_done}]

set_property IOSTANDARD LVCMOS33 [get_ports {sd_clk}]
set_property IOSTANDARD LVCMOS33 [get_ports {sd_cmd}]
set_property IOSTANDARD LVCMOS33 [get_ports {sd_data[3]}]
set_property IOSTANDARD LVCMOS33 [get_ports {sd_data[2]}]
set_property IOSTANDARD LVCMOS33 [get_ports {sd_data[1]}]
set_property IOSTANDARD LVCMOS33 [get_ports {sd_data[0]}]
set_property IOSTANDARD LVCMOS33 [get_ports {sd_detect}]

set_property IOSTANDARD LVCMOS33 [get_ports {ext1[5]}]
set_property IOSTANDARD LVCMOS33 [get_ports {ext1[4]}]
set_property IOSTANDARD LVCMOS33 [get_ports {ext1[3]}]
set_property IOSTANDARD LVCMOS33 [get_ports {ext1[2]}]
set_property IOSTANDARD LVCMOS33 [get_ports {ext1[1]}]
set_property IOSTANDARD LVCMOS33 [get_ports {ext1[0]}]

set_property IOSTANDARD LVCMOS33 [get_ports {ext2[5]}]
set_property IOSTANDARD LVCMOS33 [get_ports {ext2[4]}]
set_property IOSTANDARD LVCMOS33 [get_ports {ext2[3]}]
set_property IOSTANDARD LVCMOS33 [get_ports {ext2[2]}]
set_property IOSTANDARD LVCMOS33 [get_ports {ext2[1]}]
set_property IOSTANDARD LVCMOS33 [get_ports {ext2[0]}]

set_property IOSTANDARD LVCMOS33 [get_ports {ft_oe}]
set_property IOSTANDARD LVCMOS33 [get_ports {ft_rd}]
set_property IOSTANDARD LVCMOS33 [get_ports {ft_siwua}]
set_property IOSTANDARD LVCMOS33 [get_ports {ft_wr}]
set_property IOSTANDARD LVCMOS33 [get_ports {ft_rxf}]
set_property IOSTANDARD LVCMOS33 [get_ports {ft_clkout}]
set_property IOSTANDARD LVCMOS33 [get_ports {ft_txe}]
set_property IOSTANDARD LVCMOS33 [get_ports {ft_suspend}]

set_property IOSTANDARD LVCMOS33 [get_ports {led}]

set_property IOSTANDARD LVCMOS33 [get_ports {ft_data[7]}]
set_property IOSTANDARD LVCMOS33 [get_ports {ft_data[6]}]
set_property IOSTANDARD LVCMOS33 [get_ports {ft_data[5]}]
set_property IOSTANDARD LVCMOS33 [get_ports {ft_data[4]}]
set_property IOSTANDARD LVCMOS33 [get_ports {ft_data[3]}]
set_property IOSTANDARD LVCMOS33 [get_ports {ft_data[2]}]
set_property IOSTANDARD LVCMOS33 [get_ports {ft_data[1]}]
set_property IOSTANDARD LVCMOS33 [get_ports {ft_data[0]}]

set_property IOSTANDARD LVCMOS33 [get_ports {spi_cs}]
set_property IOSTANDARD LVCMOS33 [get_ports {spi_din}]
set_property IOSTANDARD LVCMOS33 [get_ports {spi_dout}]



set_property PACKAGE_PIN N11 [get_ports clk]

set_property PACKAGE_PIN B1 [get_ports adc_shdn[0]]
set_property PACKAGE_PIN N2 [get_ports adc_shdn[1]]
set_property PACKAGE_PIN B2 [get_ports adc_oe[0]]
set_property PACKAGE_PIN P1 [get_ports adc_oe[1]]
set_property PACKAGE_PIN C2 [get_ports adc_of[0]]

set_property PACKAGE_PIN M1 [get_ports adc_of[1]]
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

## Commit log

2017-09-27 Fix FPGA programming resistor connections
    M[2:0] were wired incorrectly when I ordered the board. For programming from SPI
    memory M[2:0] should be "001", but I had them wired backwards as "100". I fixed
    it with one jump wire, but here is a proper fix for anyone looking to reproduce
    the design.
    [fmcw3.kicad_pcb, fpga.sch]
2023-05-05 Openocd changes for the latest version
    Openocd jtagspi protocol changed a long time ago and the new version
    needs a new bitstream to program flash.
    [program_flash.cfg, program_fpga.cfg]
